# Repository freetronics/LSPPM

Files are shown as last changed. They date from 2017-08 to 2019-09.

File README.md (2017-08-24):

Freetronics LibreSat Payload Processor Module
=============================================
Copyright 2013-2017 Freetronics Pty Ltd  
Freetronics site:  www.freetronics.com  
Freetronics email: info@freetronics.com  

A CubeSat payload board that incorporates 16 processor nodes for
running experiments, and a supervisor processor node to control
the experiment nodes.

A previous version of this board flew in space on ArduSat-X and
ArduSat-1.

Features:

 * 16 x processor nodes, each with an ATmega328P MCU
 * Each processor node runs the Arduino bootloader
 * 1 x supervisor node with an ATmega2561
 * Micro SD card slot connected to supervisor
 * All MCUs and sensors on a shared I2C bus
 * All I2C devices use bidirectional isolation circuits to allow continued operation of the system with failed devices
 * Processor node UARTs connected via multiplexers to the supervisor's first UART
 * 5V serial debug console with standard FTDI-style pinout on supervisor's second UART
 * Each processor node can be powered down independently by the supervisor
 * Each processor node can be reset using an I2C latch by the supervisor
 * Each MCU has an independent crystal for maximum reliability
 * TX, RX, and D13 LEDs on every processor node
 * Top and bottom temperature sensors on I2C bus with "disable" option to prevent address collisions
 * Requires external 5V and 3.3V supply
 * Current consumption monitoring of both power rails by the supervisor
 * Stackable CubeSat bus connectors
 * Conforms to CubeSat mechanical standards for dimensions and mounting
 * Selectable power bus connections
 * Optional I2C satellite bus pull-ups
 * I2C headers for spectrometer, Geiger counter, and bottom plate sensor assembly
 * GPS header with UART connections to node 11 via 3.3V level shifters
 * Switchable power supply to GPS header controlled by supervisor
 * Stackable CubeSat Bus connectors

Specifications:

 * Dimensions: 95.45mm x 90.3mm
 * PCB material: FR4 fibreglass (requires out-gassing before vacuum use)
 * PCB finish: ENIG (electroless nickel immersion gold) recommended
 * Module mass: 37 grams
 * Connector mass (pair): 15 grams
 * Total assembled mass including solder: 54 grams

More information is available at:

  http://www.freetronics.com.au/lsppm

INSTALLATION
------------
The design is saved as an EAGLE project. EAGLE PCB design software is
available from www.cadsoftusa.com free for non-commercial use. To use
this project download it and place the directory containing these files
into the "eagle" directory on your computer. Then open EAGLE and
navigate to the project. 

DISTRIBUTION
------------
The specific terms of distribution of this project are governed by the
license referenced below.

LICENSE
-------
Licensed under the TAPR Open Hardware License (www.tapr.org/OHL).
The "license" folder within this repository also contains a copy of
this license in plain text format.

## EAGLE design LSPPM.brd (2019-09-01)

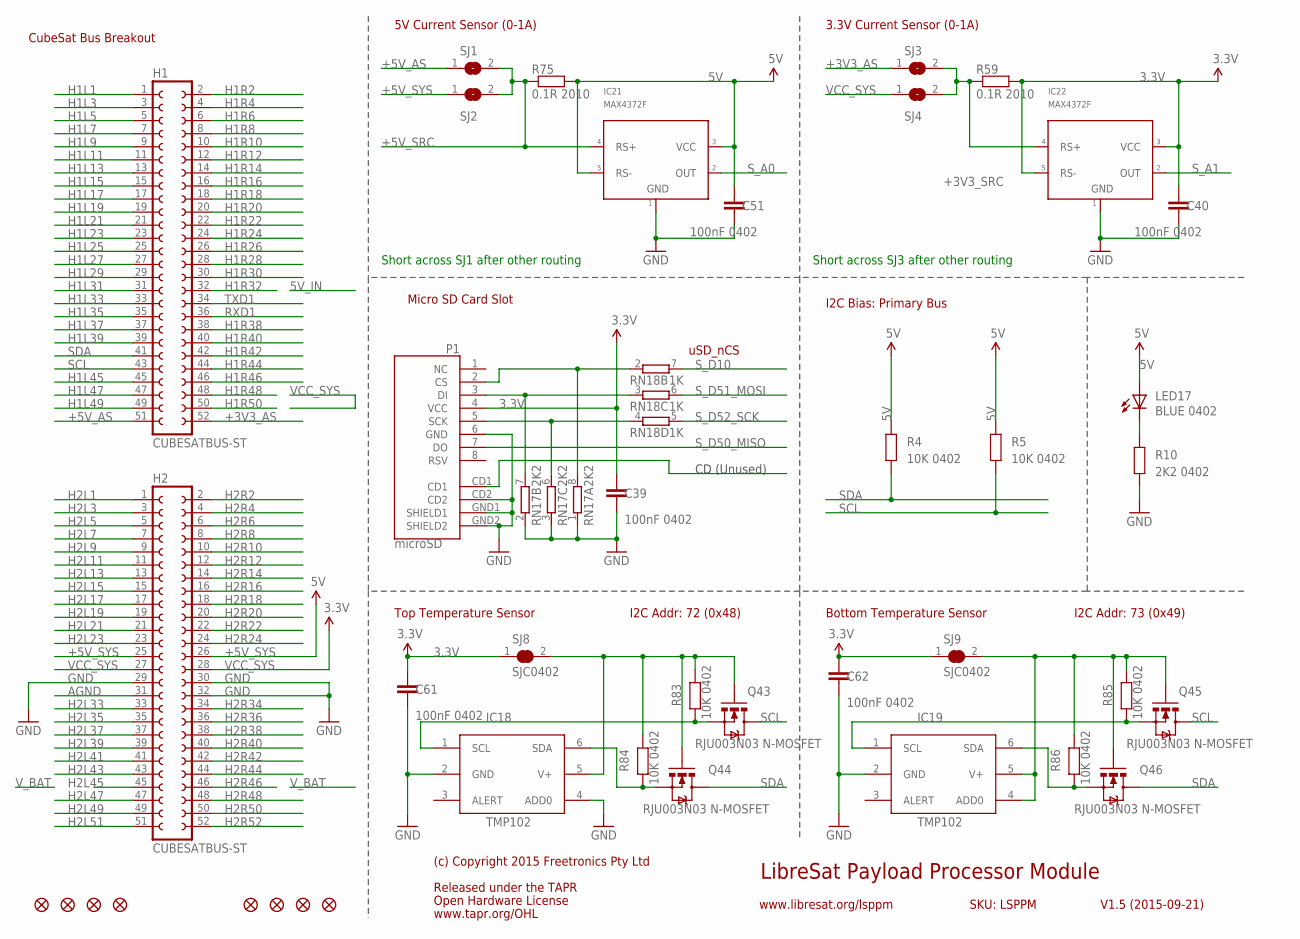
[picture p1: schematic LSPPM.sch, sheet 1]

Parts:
C39, C40, C51, C61, C62: 100nF 0402; C0402
FID1, FID2, FID3, FID4, FID5, FID6, FID7, FID8: FIDUCIAL1X2.5; FIDUCIAL-1X2.5
H1, H2: CUBESATBUS-ST
IC18, IC19: TMP102; SOT563
IC21, IC22: MAX4372F; SOT23-5
LED17: BLUE 0402; LED-0402
P1: microSD; MICRO-SD-SOCKET-PP
Q43, Q44, Q45, Q46: RJU003N03 N-MOSFET; SOT32-3
R4, R5, R83, R84, R85, R86: 10K 0402; R0402
R10: 2K2 0402; R0402
R59, R75: 0.1R 2010; R2010
RN17: 2K2; CAY16
RN18: 1K; CAY16
SJ1, SJ2, SJ3, SJ4: SJ
SJ8, SJ9: SJC0402; 0402SJC

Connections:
3.3V: C39.1, C40.1, C61.1, C62.1, IC22.3 (VCC), IC22.5 (RS-), P1.4 (VCC), R59.2, SJ8.1, SJ9.1; also elsewhere on the board
5V: C51.1, IC21.3 (VCC), IC21.5 (RS-), LED17.A, R4.2, R5.2, R75.2; also elsewhere on the board
+3V3_AS: H1.52, SJ3.1
+3V3_SRC: IC22.4 (RS+), R59.1, SJ3.2, SJ4.2
+5V_AS: H1.51, SJ1.1
+5V_SRC: IC21.4 (RS+), R75.1, SJ1.2, SJ2.2; also elsewhere on the board
+5V_SYS: H2.25, H2.26, SJ2.1
AGND: H2.31
GND: C39.2, C40.2, C51.2, C61.2, C62.2, H2.29, H2.30, H2.32, IC18.2 (GND), IC18.4 (ADD0), IC19.2 (GND), IC21.1 (GND), IC22.1 (GND), P1.6 (GND), P1.CD2, P1.GND1 (SHIELD1), P1.GND2 (SHIELD2), R10.1, RN17.1, RN17.2 (1), RN17.3 (1); also elsewhere on the board
H1L1: H1.1
H1L3: H1.3
H1L5: H1.5
H1L7: H1.7
H1L9: H1.9
H1L11: H1.11
H1L13: H1.13
H1L15: H1.15
H1L17: H1.17
H1L19: H1.19
H1L21: H1.21
H1L23: H1.23
H1L25: H1.25
H1L27: H1.27
H1L29: H1.29
H1L31: H1.31
H1L33: H1.33
H1L35: H1.35
H1L37: H1.37
H1L39: H1.39
H1L45: H1.45
H1L47: H1.47
H1L49: H1.49
H1R2: H1.2
H1R4: H1.4
H1R6: H1.6
H1R8: H1.8
H1R10: H1.10
H1R12: H1.12
H1R14: H1.14
H1R16: H1.16
H1R18: H1.18
H1R20: H1.20
H1R22: H1.22
H1R24: H1.24
H1R26: H1.26
H1R28: H1.28
H1R30: H1.30
H1R32: H1.32
H1R38: H1.38
H1R40: H1.40
H1R42: H1.42
H1R44: H1.44
H1R46: H1.46
H1R48: H1.48
H1R50: H1.50
H2L1: H2.1
H2L3: H2.3
H2L5: H2.5
H2L7: H2.7
H2L9: H2.9
H2L11: H2.11
H2L13: H2.13
H2L15: H2.15
H2L17: H2.17
H2L19: H2.19
H2L21: H2.21
H2L23: H2.23
H2L33: H2.33
H2L35: H2.35
H2L37: H2.37
H2L39: H2.39
H2L41: H2.41
H2L43: H2.43
H2L45: H2.45
H2L47: H2.47
H2L49: H2.49
H2L51: H2.51
H2R2: H2.2
H2R4: H2.4
H2R6: H2.6
H2R8: H2.8
H2R10: H2.10
H2R12: H2.12
H2R14: H2.14
H2R16: H2.16
H2R18: H2.18
H2R20: H2.20
H2R22: H2.22
H2R24: H2.24
H2R34: H2.34
H2R36: H2.36
H2R38: H2.38
H2R40: H2.40
H2R42: H2.42
H2R44: H2.44
H2R46: H2.46
H2R48: H2.48
H2R50: H2.50
H2R52: H2.52
unnamed: LED17.C, R10.2
unnamed: P1.2 (CS), RN17.8 (2), RN18.2 (1)
unnamed: P1.3 (DI), RN17.7 (2), RN18.3 (1)
unnamed: P1.5 (SCK), RN17.6 (2), RN18.4 (1)
unnamed: IC18.1 (SCL), Q43.2 (S), R83.1
unnamed: IC18.6 (SDA), Q44.2 (S), R84.1
unnamed: IC19.6 (SDA), Q46.2 (S), R86.1
unnamed: IC19.1 (SCL), Q45.2 (S), R85.1
unnamed: IC18.5 (V+), Q43.1 (G), Q44.1 (G), R83.2, R84.2, SJ8.2
unnamed: IC19.4 (ADD0), IC19.5 (V+), Q45.1 (G), Q46.1 (G), R85.2, R86.2, SJ9.2
RXD1: H1.36; also elsewhere on the board
SCL: H1.43, Q43.3 (D), Q45.3 (D), R5.1; also elsewhere on the board
SDA: H1.41, Q44.3 (D), Q46.3 (D), R4.1; also elsewhere on the board
S_A0: IC21.2 (OUT); also elsewhere on the board
S_A1: IC22.2 (OUT); also elsewhere on the board
S_D10: RN18.7 (2); also elsewhere on the board
S_D50_MISO: P1.7 (DO); also elsewhere on the board
S_D51_MOSI: RN18.6 (2); also elsewhere on the board
S_D52_SCK: RN18.5 (2); also elsewhere on the board
TXD1: H1.34; also elsewhere on the board
VCC_SYS: H2.27, H2.28, SJ4.1

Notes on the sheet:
LibreSat Payload Processor Module
V1.5 (2015-09-21)
www.libresat.org/lsppm
SKU: LSPPM
CubeSat Bus Breakout
Released under the TAPR
Open Hardware License
www.tapr.org/OHL
(c) Copyright 2015 Freetronics Pty Ltd
I2C Bias: Primary Bus
5V Current Sensor (0-1A)
3.3V Current Sensor (0-1A)
Top Temperature Sensor
Bottom Temperature Sensor
I2C Addr: 72 (0x48)
I2C Addr: 73 (0x49)
Short across SJ1 after other routing
uSD_nCS
Micro SD Card Slot
CD (Unused)
Short across SJ3 after other routing

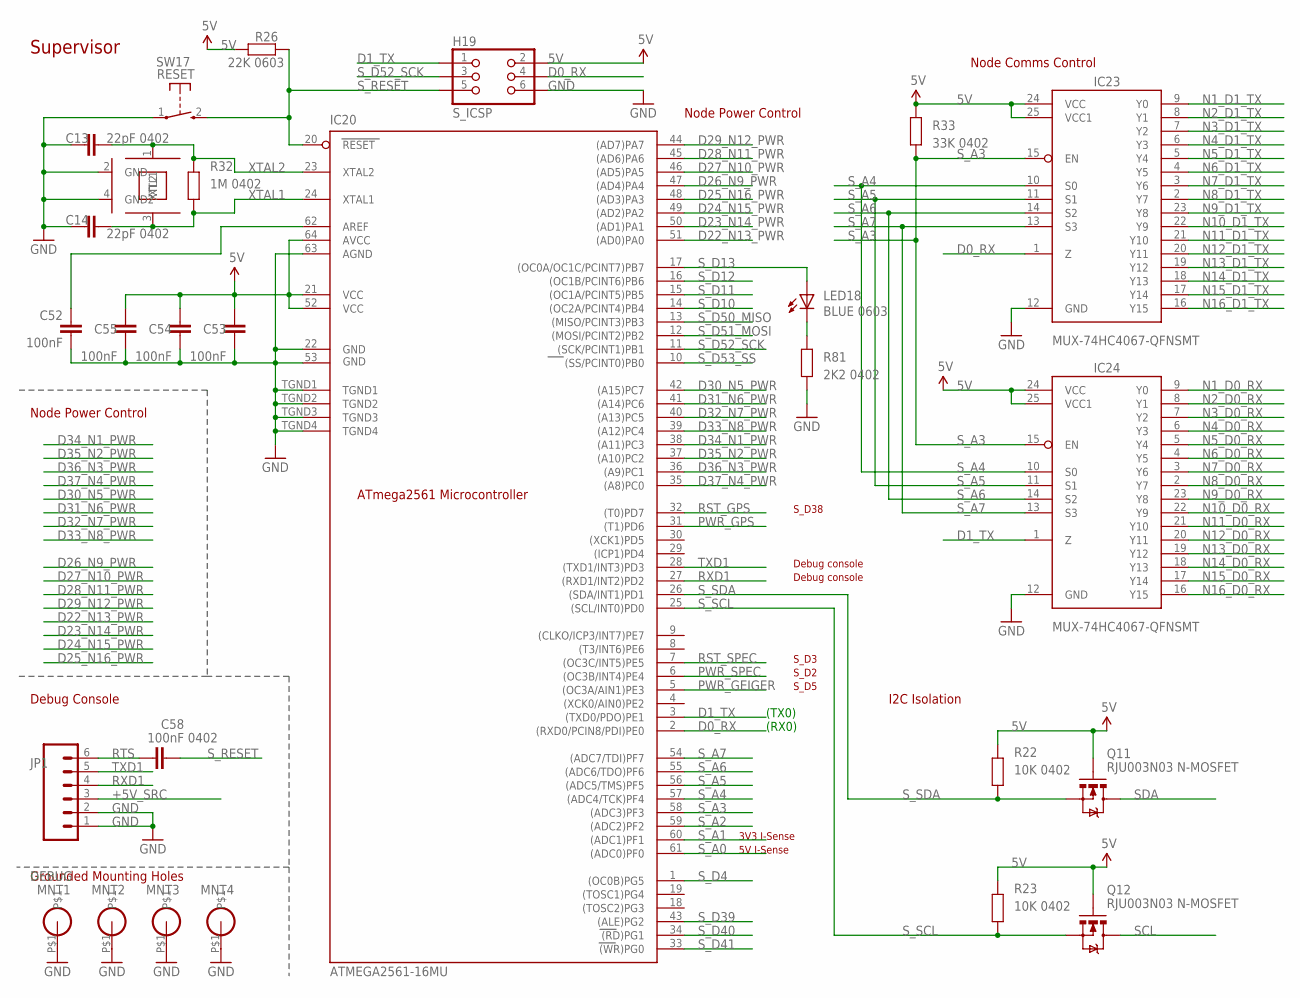
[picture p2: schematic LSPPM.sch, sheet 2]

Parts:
C13, C14: 22pF 0402; C0402
C52, C53, C54, C55: 100nF; C0402
C58: 100nF 0402; C0402
H19: S_ICSP; 2X03-ICSP
IC20: ATMEGA2561-16MU; MLF64
IC23, IC24: MUX-74HC4067-QFNSMT; DHVQFN24
JP1: DEBUG; 1X06-P-RA
LED18: BLUE 0603; LED-0402
MNT1, MNT2, MNT3, MNT4: HOLE3.2MM; HOLE32
Q11, Q12: RJU003N03 N-MOSFET; SOT32-3
R22, R23: 10K 0402; R0402
R26: 22K 0603; R0402
R32: 1M 0402; R0402
R33: 33K 0402; R0402
R81: 2K2 0402; R0402
SW17: RESET; TACTILE_SMT_3X4X2
XTL17: SMD3225-16MHZ 3.2 x 2.5mm crystal; CRYSTAL-SMD-3X2

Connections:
5V: C53.1, C54.1, C55.1, H19.2, IC20.21 (VCC), IC20.52 (VCC1), IC20.64 (AVCC), IC23.24 (VCC), IC23.25 (VCC1), IC24.24 (VCC), IC24.25 (VCC1), Q11.1 (G), Q12.1 (G), R22.2, R23.2, R26.2, R33.2; also elsewhere on the board
+5V_SRC: JP1.3; also elsewhere on the board
D0_RX: H19.4, IC20.2 ((RXD0/PCIN8/PDI)PE0), IC23.1 (Z)
D1_TX: H19.1, IC20.3 ((TXD0/PDO)PE1), IC24.1 (Z)
D22_N13_PWR: IC20.51 ((AD0)PA0); also elsewhere on the board
D23_N14_PWR: IC20.50 ((AD1)PA1); also elsewhere on the board
D24_N15_PWR: IC20.49 ((AD2)PA2); also elsewhere on the board
D25_N16_PWR: IC20.48 ((AD3)PA3); also elsewhere on the board
D26_N9_PWR: IC20.47 ((AD4)PA4); also elsewhere on the board
D27_N10_PWR: IC20.46 ((AD5)PA5); also elsewhere on the board
D28_N11_PWR: IC20.45 ((AD6)PA6); also elsewhere on the board
D29_N12_PWR: IC20.44 ((AD7)PA7); also elsewhere on the board
D30_N5_PWR: IC20.42 ((A15)PC7); also elsewhere on the board
D31_N6_PWR: IC20.41 ((A14)PC6); also elsewhere on the board
D32_N7_PWR: IC20.40 ((A13)PC5); also elsewhere on the board
D33_N8_PWR: IC20.39 ((A12)PC4); also elsewhere on the board
D34_N1_PWR: IC20.38 ((A11)PC3); also elsewhere on the board
D35_N2_PWR: IC20.37 ((A10)PC2); also elsewhere on the board
D36_N3_PWR: IC20.36 ((A9)PC1); also elsewhere on the board
D37_N4_PWR: IC20.35 ((A8)PC0); also elsewhere on the board
GND: C13.1, C14.1, C52.2, C53.2, C54.2, C55.2, H19.6, IC20.22 (GND), IC20.53 (GND1), IC20.63 (AGND), IC20.TGND1, IC20.TGND2, IC20.TGND3, IC20.TGND4, IC23.12 (GND), IC24.12 (GND), JP1.1, JP1.2, MNT1.P$1, MNT2.P$1, MNT3.P$1, MNT4.P$1, R81.1, SW17.1, XTL17.2 (GND), XTL17.4 (GND2); also elsewhere on the board
N1_D0_RX: IC24.9 (Y0); also elsewhere on the board
N1_D1_TX: IC23.9 (Y0); also elsewhere on the board
N2_D0_RX: IC24.8 (Y1); also elsewhere on the board
N2_D1_TX: IC23.8 (Y1); also elsewhere on the board
N3_D0_RX: IC24.7 (Y2); also elsewhere on the board
N3_D1_TX: IC23.7 (Y2); also elsewhere on the board
N4_D0_RX: IC24.6 (Y3); also elsewhere on the board
N4_D1_TX: IC23.6 (Y3); also elsewhere on the board
N5_D0_RX: IC24.5 (Y4); also elsewhere on the board
N5_D1_TX: IC23.5 (Y4); also elsewhere on the board
N6_D0_RX: IC24.4 (Y5); also elsewhere on the board
N6_D1_TX: IC23.4 (Y5); also elsewhere on the board
N7_D0_RX: IC24.3 (Y6); also elsewhere on the board
N7_D1_TX: IC23.3 (Y6); also elsewhere on the board
N8_D0_RX: IC24.2 (Y7); also elsewhere on the board
N8_D1_TX: IC23.2 (Y7); also elsewhere on the board
N9_D0_RX: IC24.23 (Y8); also elsewhere on the board
N9_D1_TX: IC23.23 (Y8); also elsewhere on the board
N10_D0_RX: IC24.22 (Y9); also elsewhere on the board
N10_D1_TX: IC23.22 (Y9); also elsewhere on the board
N11_D0_RX: IC24.21 (Y10); also elsewhere on the board
N11_D1_TX: IC23.21 (Y10); also elsewhere on the board
N12_D0_RX: IC24.20 (Y11); also elsewhere on the board
N12_D1_TX: IC23.20 (Y11); also elsewhere on the board
N13_D0_RX: IC24.19 (Y12); also elsewhere on the board
N13_D1_TX: IC23.19 (Y12); also elsewhere on the board
N14_D0_RX: IC24.18 (Y13); also elsewhere on the board
N14_D1_TX: IC23.18 (Y13); also elsewhere on the board
N15_D0_RX: IC24.17 (Y14); also elsewhere on the board
N15_D1_TX: IC23.17 (Y14); also elsewhere on the board
N16_D0_RX: IC24.16 (Y15); also elsewhere on the board
N16_D1_TX: IC23.16 (Y15); also elsewhere on the board
unnamed: C52.1, IC20.62 (AREF)
unnamed: LED18.C, R81.2
PWR_GEIGER: IC20.5 ((OC3A/AIN1)PE3); also elsewhere on the board
PWR_GPS: IC20.31 ((T1)PD6); also elsewhere on the board
PWR_SPEC: IC20.6 ((OC3B/INT4)PE4); also elsewhere on the board
RST_GPS: IC20.32 ((T0)PD7); also elsewhere on the board
RST_SPEC: IC20.7 ((OC3C/INT5)PE5); also elsewhere on the board
RTS: C58.1, JP1.6
RXD1: IC20.27 ((RXD1/INT2)PD2), JP1.4; also elsewhere on the board
SCL: Q12.3 (D); also elsewhere on the board
SDA: Q11.3 (D); also elsewhere on the board
S_A0: IC20.61 ((ADC0)PF0); also elsewhere on the board
S_A1: IC20.60 ((ADC1)PF1); also elsewhere on the board
S_A2: IC20.59 ((ADC2)PF2)
S_A3: IC20.58 ((ADC3)PF3), IC23.15 (EN), IC24.15 (EN), R33.1
S_A4: IC20.57 ((ADC4/TCK)PF4), IC23.10 (S0), IC24.10 (S0)
S_A5: IC20.56 ((ADC5/TMS)PF5), IC23.11 (S1), IC24.11 (S1)
S_A6: IC20.55 ((ADC6/TDO)PF6), IC23.14 (S2), IC24.14 (S2)
S_A7: IC20.54 ((ADC7/TDI)PF7), IC23.13 (S3), IC24.13 (S3)
S_D4: IC20.1 ((OC0B)PG5)
S_D10: IC20.14 ((OC2A/PCINT4)PB4); also elsewhere on the board
S_D11: IC20.15 ((OC1A/PCINT5)PB5)
S_D12: IC20.16 ((OC1B/PCINT6)PB6)
S_D13: IC20.17 ((OC0A/OC1C/PCINT7)PB7), LED18.A
S_D39: IC20.43 ((ALE)PG2)
S_D40: IC20.34 ((RD)PG1)
S_D41: IC20.33 ((WR)PG0)
S_D50_MISO: IC20.13 ((MISO/PCINT3)PB3); also elsewhere on the board
S_D51_MOSI: IC20.12 ((MOSI/PCINT2)PB2); also elsewhere on the board
S_D52_SCK: H19.3, IC20.11 ((SCK/PCINT1)PB1); also elsewhere on the board
S_D53_SS: IC20.10 ((SS/PCINT0)PB0)
S_RESET: C58.2, H19.5, IC20.20 (RESET), R26.1, SW17.2 (S)
S_SCL: IC20.25 ((SCL/INT0)PD0), Q12.2 (S), R23.1
S_SDA: IC20.26 ((SDA/INT1)PD1), Q11.2 (S), R22.1
TXD1: IC20.28 ((TXD1/INT3)PD3), JP1.5; also elsewhere on the board
XTAL1: C14.2, IC20.24 (XTAL1), R32.1, XTL17.3 (XTL2)
XTAL2: C13.2, IC20.23 (XTAL2), R32.2, XTL17.1 (XTL1)

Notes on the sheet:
Supervisor
Node Comms Control
Node Power Control
I2C Isolation
ATmega2561 Microcontroller
(TX0)
(RX0)
Grounded Mounting Holes
Debug Console
5V I-Sense
3V3 I-Sense
S_D5
S_D2
S_D3
Debug console
S_D38

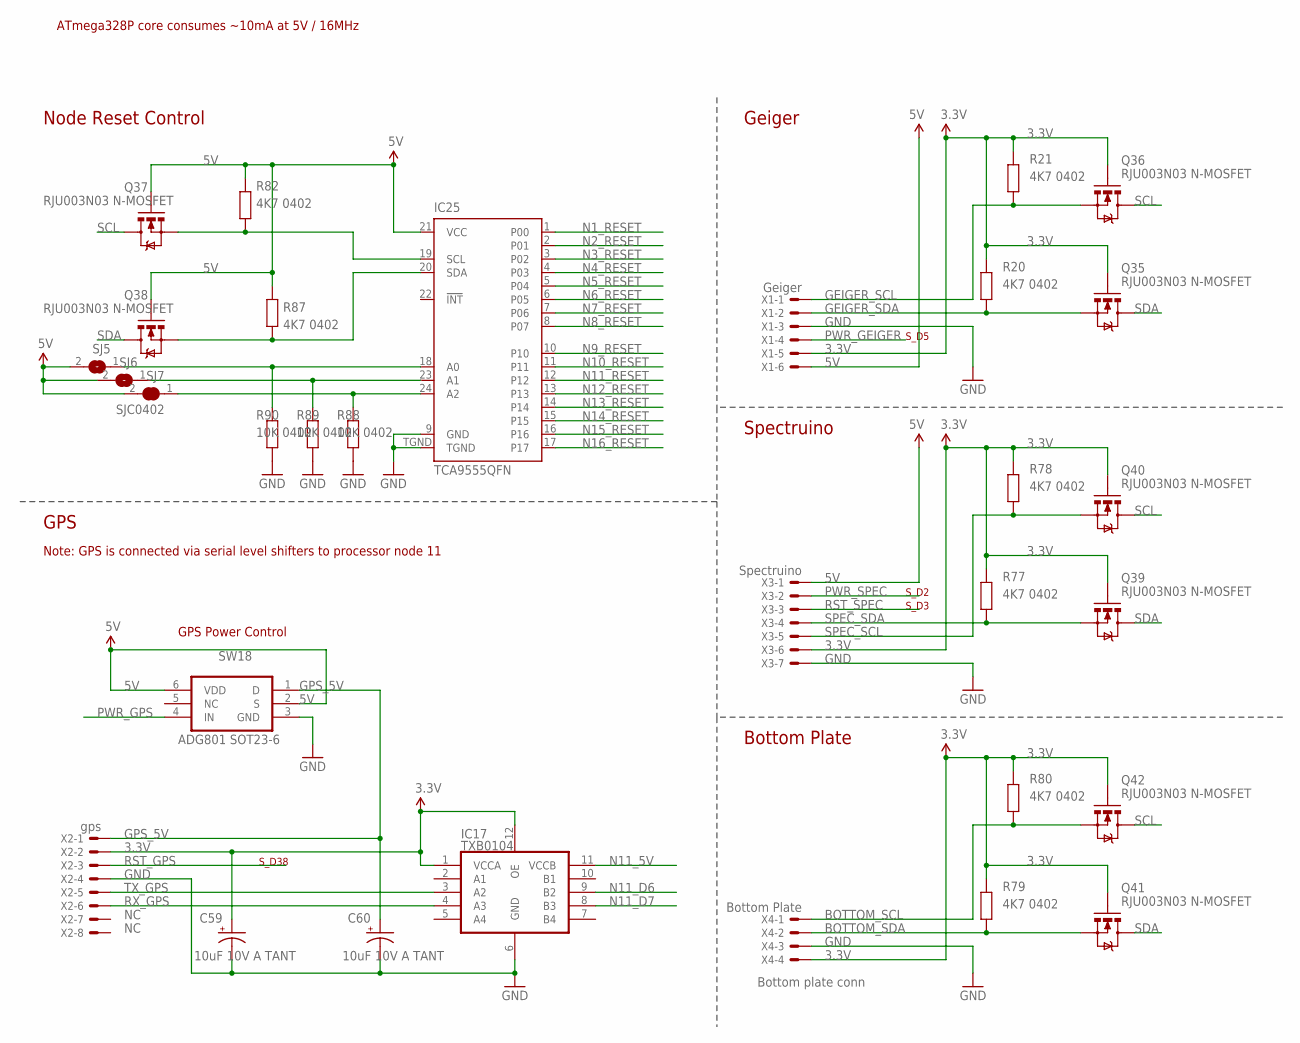
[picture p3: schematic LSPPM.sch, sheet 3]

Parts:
C59, C60: 10uF 10V A TANT; EIA3216
IC17: TXB0104; QFN-12
IC25: TCA9555QFN; QFN-24
Q35, Q36, Q37, Q38, Q39, Q40, Q41, Q42: RJU003N03 N-MOSFET; SOT32-3
R20, R21, R77, R78, R79, R80, R82, R87: 4K7 0402; R0402
R88, R89, R90: 10K 0402; R0402
SJ5, SJ6: SJ0402O; 0402SJO
SJ7: SJC0402; 0402SJC
SW18: ADG801 SOT23-6; SOT23-6
X1: Geiger; 53398-06
X2: gps; 53398-08
X3: Spectruino; 53398-07
X4: Bottom Plate; 53398-04

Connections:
3.3V: C59.A (+), IC17.1 (VCCA), IC17.12 (OE), Q35.1 (G), Q36.1 (G), Q39.1 (G), Q40.1 (G), Q41.1 (G), Q42.1 (G), R20.2, R21.2, R77.2, R78.2, R79.2, R80.2, X1.5, X2.2, X3.6, X4.4; also elsewhere on the board
5V: IC25.21 (VCC), Q37.1 (G), Q38.1 (G), R82.2, R87.2, SJ5.2, SJ6.2, SJ7.2, SW18.2 (S), SW18.6 (VDD), X1.6, X3.1; also elsewhere on the board
BOTTOM_SCL: Q42.2 (S), R80.1, X4.1
BOTTOM_SDA: Q41.2 (S), R79.1, X4.2
GEIGER_SCL: Q36.2 (S), R21.1, X1.1
GEIGER_SDA: Q35.2 (S), R20.1, X1.2
GND: C59.C (-), C60.C (-), IC17.6 (GND), IC25.9 (GND), IC25.TGND, R88.1, R89.1, R90.1, SW18.3 (GND), X1.3, X2.4, X3.7, X4.3; also elsewhere on the board
GPS_5V: C60.A (+), SW18.1 (D), X2.1
N1_RESET: IC25.1 (P00); also elsewhere on the board
N2_RESET: IC25.2 (P01); also elsewhere on the board
N3_RESET: IC25.3 (P02); also elsewhere on the board
N4_RESET: IC25.4 (P03); also elsewhere on the board
N5_RESET: IC25.5 (P04); also elsewhere on the board
N6_RESET: IC25.6 (P05); also elsewhere on the board
N7_RESET: IC25.7 (P06); also elsewhere on the board
N8_RESET: IC25.8 (P07); also elsewhere on the board
N9_RESET: IC25.10; also elsewhere on the board
N10_RESET: IC25.11; also elsewhere on the board
N11_5V: IC17.11 (VCCB); also elsewhere on the board
N11_D6: IC17.9 (B2); also elsewhere on the board
N11_D7: IC17.8 (B3); also elsewhere on the board
N11_RESET: IC25.12; also elsewhere on the board
N12_RESET: IC25.13; also elsewhere on the board
N13_RESET: IC25.14; also elsewhere on the board
N14_RESET: IC25.15; also elsewhere on the board
N15_RESET: IC25.16; also elsewhere on the board
N16_RESET: IC25.17; also elsewhere on the board
unnamed: IC25.18 (A0), R90.2, SJ5.1
unnamed: IC25.23 (A1), R89.2, SJ6.1
unnamed: IC25.24 (A2), R88.2, SJ7.1
unnamed: IC25.19 (SCL), Q37.2 (S), R82.1
unnamed: IC25.20 (SDA), Q38.2 (S), R87.1
PWR_GEIGER: X1.4; also elsewhere on the board
PWR_GPS: SW18.4 (IN); also elsewhere on the board
PWR_SPEC: X3.2; also elsewhere on the board
RST_GPS: X2.3; also elsewhere on the board
RST_SPEC: X3.3; also elsewhere on the board
RX_GPS: IC17.4 (A3), X2.6
SCL: Q36.3 (D), Q37.3 (D), Q40.3 (D), Q42.3 (D); also elsewhere on the board
SDA: Q35.3 (D), Q38.3 (D), Q39.3 (D), Q41.3 (D); also elsewhere on the board
SPEC_SCL: Q40.2 (S), R78.1, X3.5
SPEC_SDA: Q39.2 (S), R77.1, X3.4
TX_GPS: IC17.3 (A2), X2.5

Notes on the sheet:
Node Reset Control
Bottom plate conn
Geiger
Spectruino
Bottom Plate
GPS
Note: GPS is connected via serial level shifters to processor node 11
S_D3
S_D2
S_D5
ATmega328P core consumes ~10mA at 5V / 16MHz
S_D38
GPS Power Control

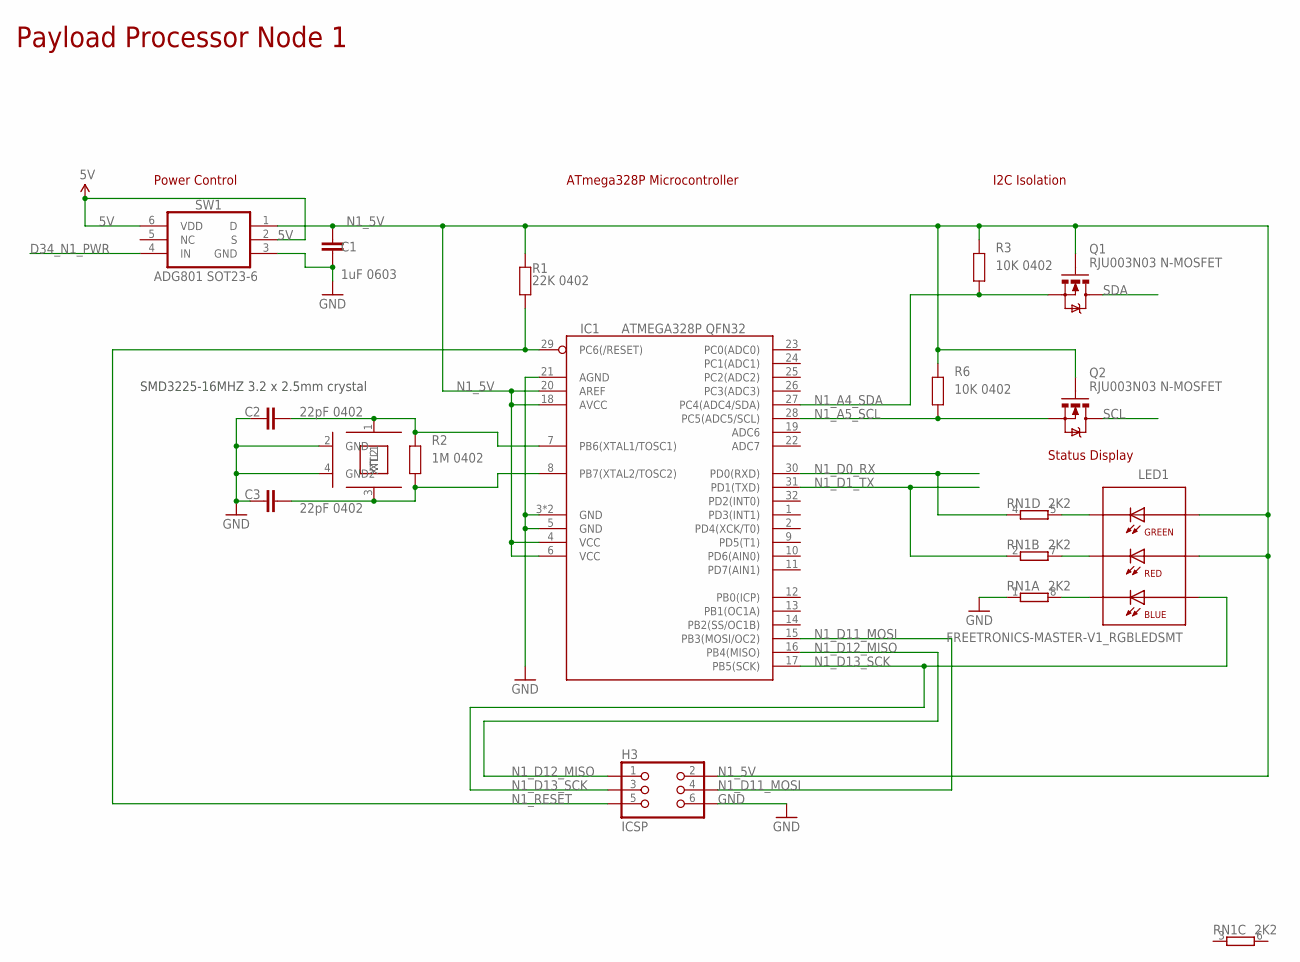
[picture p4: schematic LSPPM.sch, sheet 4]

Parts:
C1: 1uF 0603; C0603
C2, C3: 22pF 0402; C0402
H3: ICSP; M2X3-2MM
IC1: ATMEGA328P QFN32; MLF32
LED1: FREETRONICS-MASTER-V1_RGBLEDSMT; FREETRONICS-MASTER-V1_19-337
Q1, Q2: RJU003N03 N-MOSFET; SOT32-3
R1: 22K 0402; R0402
R2: 1M 0402; R0402
R3, R6: 10K 0402; R0402
RN1: 2K2; CAY16
SW1: ADG801 SOT23-6; SOT23-6
XTL1: SMD3225-16MHZ 3.2 x 2.5mm crystal; CRYSTAL-SMD-3X2

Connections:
5V: SW1.2 (S), SW1.6 (VDD); also elsewhere on the board
D34_N1_PWR: SW1.4 (IN); also elsewhere on the board
GND: C1.2, C2.1, C3.1, H3.6, IC1.3 (GND), IC1.5 (GND), IC1.21 (AGND), IC1.TGND (GND), RN1.1, SW1.3 (GND), XTL1.2 (GND), XTL1.4 (GND2); also elsewhere on the board
N1_5V: C1.1, H3.2, IC1.4 (VCC), IC1.6 (VCC), IC1.18 (AVCC), IC1.20 (AREF), LED1.5 (A-R), LED1.6 (A-G), Q1.1 (G), Q2.1 (G), R1.2, R3.2, R6.2, SW1.1 (D)
N1_A4_SDA: IC1.27 (PC4(ADC4/SDA)), Q1.2 (S), R3.1
N1_A5_SCL: IC1.28 (PC5(ADC5/SCL)), Q2.2 (S), R6.1
N1_D0_RX: IC1.30 (PD0(RXD)), RN1.4 (1); also elsewhere on the board
N1_D1_TX: IC1.31 (PD1(TXD)), RN1.2 (1); also elsewhere on the board
N1_D11_MOSI: H3.4, IC1.15 (PB3(MOSI/OC2))
N1_D12_MISO: H3.1, IC1.16 (PB4(MISO))
N1_D13_SCK: H3.3, IC1.17 (PB5(SCK)), LED1.4 (A-B)
N1_RESET: H3.5, IC1.29 (PC6(/RESET)), R1.1; also elsewhere on the board
unnamed: LED1.3 (C-G), RN1.5 (2)
unnamed: C3.2, IC1.8 (PB7(XTAL2/TOSC2)), R2.1, XTL1.3 (XTL2)
unnamed: C2.2, IC1.7 (PB6(XTAL1/TOSC1)), R2.2, XTL1.1 (XTL1)
unnamed: LED1.2 (C-R), RN1.7 (2)
unnamed: LED1.1 (C-B), RN1.8 (2)
SCL: Q2.3 (D); also elsewhere on the board
SDA: Q1.3 (D); also elsewhere on the board

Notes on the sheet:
Payload Processor Node 1
ATmega328P Microcontroller
I2C Isolation
Status Display
Power Control
SMD3225-16MHZ 3.2 x 2.5mm crystal

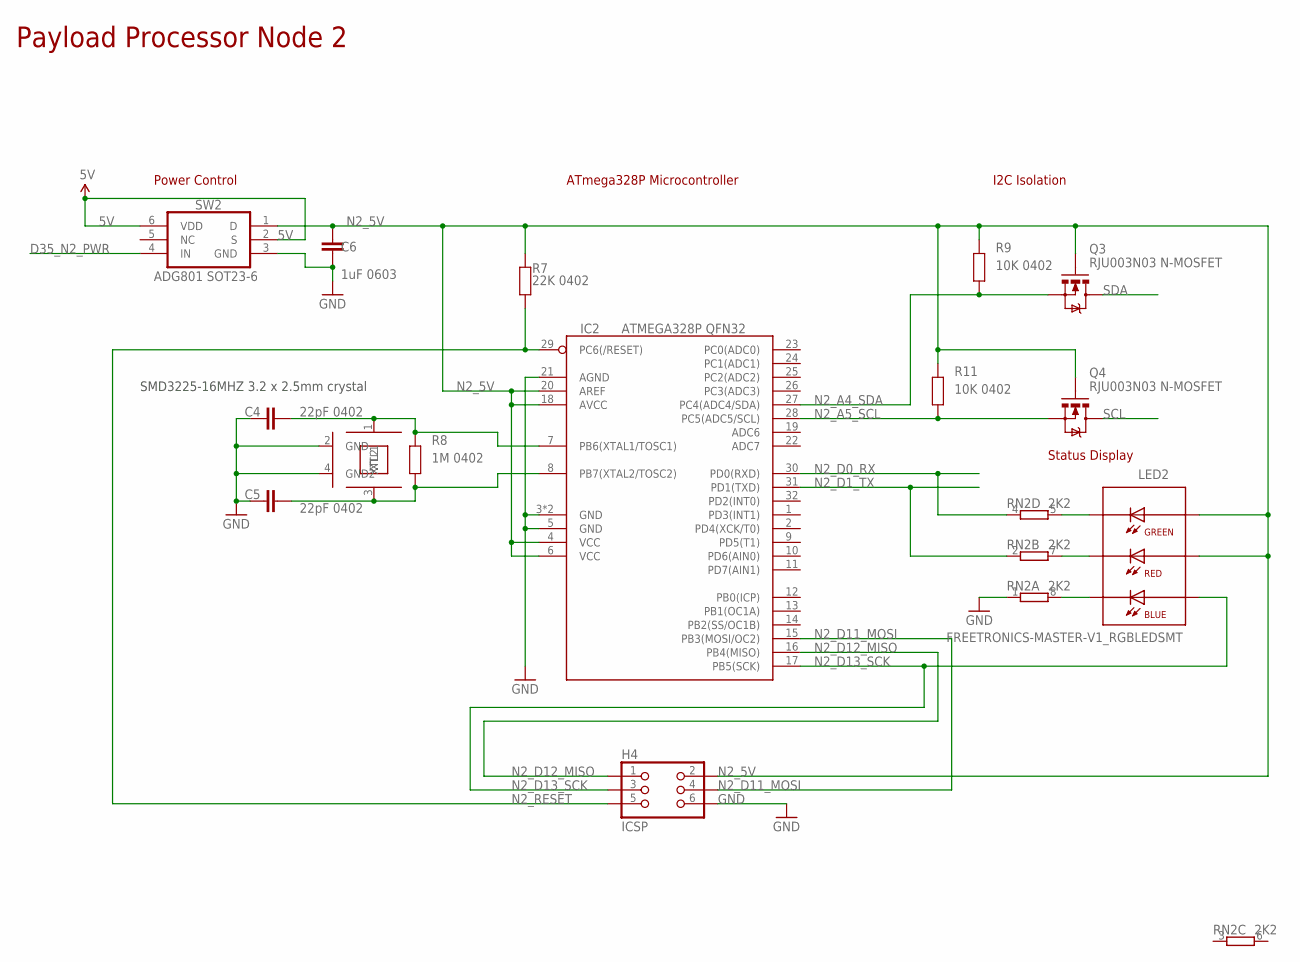
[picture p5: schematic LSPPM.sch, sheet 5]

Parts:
C4, C5: 22pF 0402; C0402
C6: 1uF 0603; C0603
H4: ICSP; M2X3-2MM
IC2: ATMEGA328P QFN32; MLF32
LED2: FREETRONICS-MASTER-V1_RGBLEDSMT; FREETRONICS-MASTER-V1_19-337
Q3, Q4: RJU003N03 N-MOSFET; SOT32-3
R7: 22K 0402; R0402
R8: 1M 0402; R0402
R9, R11: 10K 0402; R0402
RN2: 2K2; CAY16
SW2: ADG801 SOT23-6; SOT23-6
XTL2: SMD3225-16MHZ 3.2 x 2.5mm crystal; CRYSTAL-SMD-3X2

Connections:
5V: SW2.2 (S), SW2.6 (VDD); also elsewhere on the board
D35_N2_PWR: SW2.4 (IN); also elsewhere on the board
GND: C4.1, C5.1, C6.2, H4.6, IC2.3 (GND), IC2.5 (GND), IC2.21 (AGND), IC2.TGND (GND), RN2.1, SW2.3 (GND), XTL2.2 (GND), XTL2.4 (GND2); also elsewhere on the board
N2_5V: C6.1, H4.2, IC2.4 (VCC), IC2.6 (VCC), IC2.18 (AVCC), IC2.20 (AREF), LED2.5 (A-R), LED2.6 (A-G), Q3.1 (G), Q4.1 (G), R7.2, R9.2, R11.2, SW2.1 (D)
N2_A4_SDA: IC2.27 (PC4(ADC4/SDA)), Q3.2 (S), R9.1
N2_A5_SCL: IC2.28 (PC5(ADC5/SCL)), Q4.2 (S), R11.1
N2_D0_RX: IC2.30 (PD0(RXD)), RN2.4 (1); also elsewhere on the board
N2_D1_TX: IC2.31 (PD1(TXD)), RN2.2 (1); also elsewhere on the board
N2_D11_MOSI: H4.4, IC2.15 (PB3(MOSI/OC2))
N2_D12_MISO: H4.1, IC2.16 (PB4(MISO))
N2_D13_SCK: H4.3, IC2.17 (PB5(SCK)), LED2.4 (A-B)
N2_RESET: H4.5, IC2.29 (PC6(/RESET)), R7.1; also elsewhere on the board
unnamed: C5.2, IC2.8 (PB7(XTAL2/TOSC2)), R8.1, XTL2.3 (XTL2)
unnamed: C4.2, IC2.7 (PB6(XTAL1/TOSC1)), R8.2, XTL2.1 (XTL1)
unnamed: LED2.2 (C-R), RN2.7 (2)
unnamed: LED2.1 (C-B), RN2.8 (2)
unnamed: LED2.3 (C-G), RN2.5 (2)
SCL: Q4.3 (D); also elsewhere on the board
SDA: Q3.3 (D); also elsewhere on the board

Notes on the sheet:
Payload Processor Node 2
ATmega328P Microcontroller
I2C Isolation
Status Display
Power Control
SMD3225-16MHZ 3.2 x 2.5mm crystal

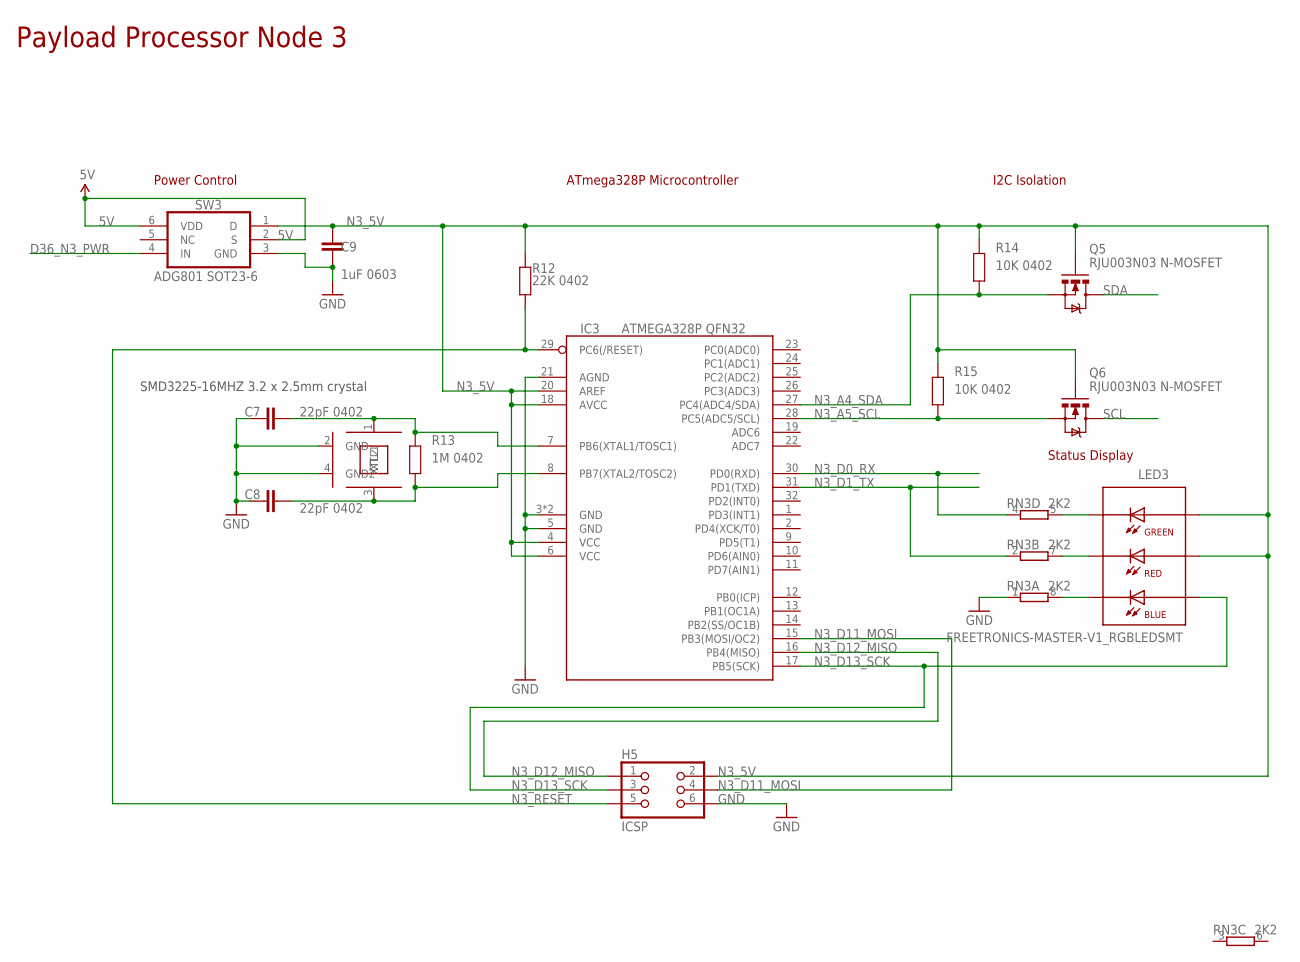
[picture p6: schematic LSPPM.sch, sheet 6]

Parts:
C7, C8: 22pF 0402; C0402
C9: 1uF 0603; C0603
H5: ICSP; M2X3-2MM
IC3: ATMEGA328P QFN32; MLF32
LED3: FREETRONICS-MASTER-V1_RGBLEDSMT; FREETRONICS-MASTER-V1_19-337
Q5, Q6: RJU003N03 N-MOSFET; SOT32-3
R12: 22K 0402; R0402
R13: 1M 0402; R0402
R14, R15: 10K 0402; R0402
RN3: 2K2; CAY16
SW3: ADG801 SOT23-6; SOT23-6
XTL3: SMD3225-16MHZ 3.2 x 2.5mm crystal; CRYSTAL-SMD-3X2

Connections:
5V: SW3.2 (S), SW3.6 (VDD); also elsewhere on the board
D36_N3_PWR: SW3.4 (IN); also elsewhere on the board
GND: C7.1, C8.1, C9.2, H5.6, IC3.3 (GND), IC3.5 (GND), IC3.21 (AGND), IC3.TGND (GND), RN3.1, SW3.3 (GND), XTL3.2 (GND), XTL3.4 (GND2); also elsewhere on the board
N3_5V: C9.1, H5.2, IC3.4 (VCC), IC3.6 (VCC), IC3.18 (AVCC), IC3.20 (AREF), LED3.5 (A-R), LED3.6 (A-G), Q5.1 (G), Q6.1 (G), R12.2, R14.2, R15.2, SW3.1 (D)
N3_A4_SDA: IC3.27 (PC4(ADC4/SDA)), Q5.2 (S), R14.1
N3_A5_SCL: IC3.28 (PC5(ADC5/SCL)), Q6.2 (S), R15.1
N3_D0_RX: IC3.30 (PD0(RXD)), RN3.4 (1); also elsewhere on the board
N3_D1_TX: IC3.31 (PD1(TXD)), RN3.2 (1); also elsewhere on the board
N3_D11_MOSI: H5.4, IC3.15 (PB3(MOSI/OC2))
N3_D12_MISO: H5.1, IC3.16 (PB4(MISO))
N3_D13_SCK: H5.3, IC3.17 (PB5(SCK)), LED3.4 (A-B)
N3_RESET: H5.5, IC3.29 (PC6(/RESET)), R12.1; also elsewhere on the board
unnamed: C8.2, IC3.8 (PB7(XTAL2/TOSC2)), R13.1, XTL3.3 (XTL2)
unnamed: C7.2, IC3.7 (PB6(XTAL1/TOSC1)), R13.2, XTL3.1 (XTL1)
unnamed: LED3.2 (C-R), RN3.7 (2)
unnamed: LED3.1 (C-B), RN3.8 (2)
unnamed: LED3.3 (C-G), RN3.5 (2)
SCL: Q6.3 (D); also elsewhere on the board
SDA: Q5.3 (D); also elsewhere on the board

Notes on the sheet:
Payload Processor Node 3
ATmega328P Microcontroller
I2C Isolation
Status Display
Power Control
SMD3225-16MHZ 3.2 x 2.5mm crystal

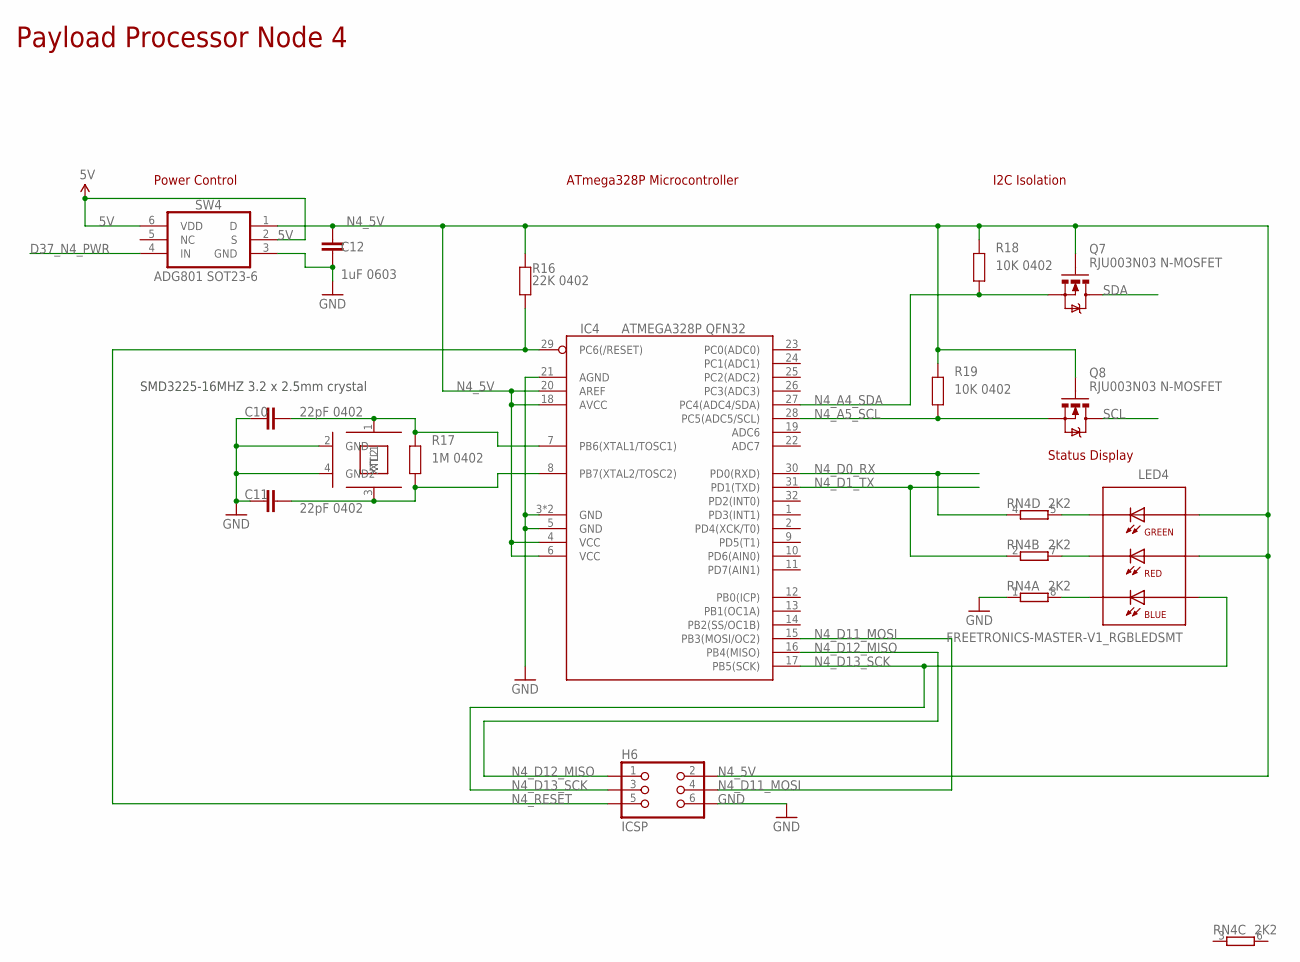
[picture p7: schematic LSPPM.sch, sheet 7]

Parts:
C10, C11: 22pF 0402; C0402
C12: 1uF 0603; C0603
H6: ICSP; M2X3-2MM
IC4: ATMEGA328P QFN32; MLF32
LED4: FREETRONICS-MASTER-V1_RGBLEDSMT; FREETRONICS-MASTER-V1_19-337
Q7, Q8: RJU003N03 N-MOSFET; SOT32-3
R16: 22K 0402; R0402
R17: 1M 0402; R0402
R18, R19: 10K 0402; R0402
RN4: 2K2; CAY16
SW4: ADG801 SOT23-6; SOT23-6
XTL4: SMD3225-16MHZ 3.2 x 2.5mm crystal; CRYSTAL-SMD-3X2

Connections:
5V: SW4.2 (S), SW4.6 (VDD); also elsewhere on the board
D37_N4_PWR: SW4.4 (IN); also elsewhere on the board
GND: C10.1, C11.1, C12.2, H6.6, IC4.3 (GND), IC4.5 (GND), IC4.21 (AGND), IC4.TGND (GND), RN4.1, SW4.3 (GND), XTL4.2 (GND), XTL4.4 (GND2); also elsewhere on the board
N4_5V: C12.1, H6.2, IC4.4 (VCC), IC4.6 (VCC), IC4.18 (AVCC), IC4.20 (AREF), LED4.5 (A-R), LED4.6 (A-G), Q7.1 (G), Q8.1 (G), R16.2, R18.2, R19.2, SW4.1 (D)
N4_A4_SDA: IC4.27 (PC4(ADC4/SDA)), Q7.2 (S), R18.1
N4_A5_SCL: IC4.28 (PC5(ADC5/SCL)), Q8.2 (S), R19.1
N4_D0_RX: IC4.30 (PD0(RXD)), RN4.4 (1); also elsewhere on the board
N4_D1_TX: IC4.31 (PD1(TXD)), RN4.2 (1); also elsewhere on the board
N4_D11_MOSI: H6.4, IC4.15 (PB3(MOSI/OC2))
N4_D12_MISO: H6.1, IC4.16 (PB4(MISO))
N4_D13_SCK: H6.3, IC4.17 (PB5(SCK)), LED4.4 (A-B)
N4_RESET: H6.5, IC4.29 (PC6(/RESET)), R16.1; also elsewhere on the board
unnamed: C11.2, IC4.8 (PB7(XTAL2/TOSC2)), R17.1, XTL4.3 (XTL2)
unnamed: C10.2, IC4.7 (PB6(XTAL1/TOSC1)), R17.2, XTL4.1 (XTL1)
unnamed: LED4.2 (C-R), RN4.7 (2)
unnamed: LED4.1 (C-B), RN4.8 (2)
unnamed: LED4.3 (C-G), RN4.5 (2)
SCL: Q8.3 (D); also elsewhere on the board
SDA: Q7.3 (D); also elsewhere on the board

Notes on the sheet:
Payload Processor Node 4
ATmega328P Microcontroller
I2C Isolation
Status Display
Power Control
SMD3225-16MHZ 3.2 x 2.5mm crystal

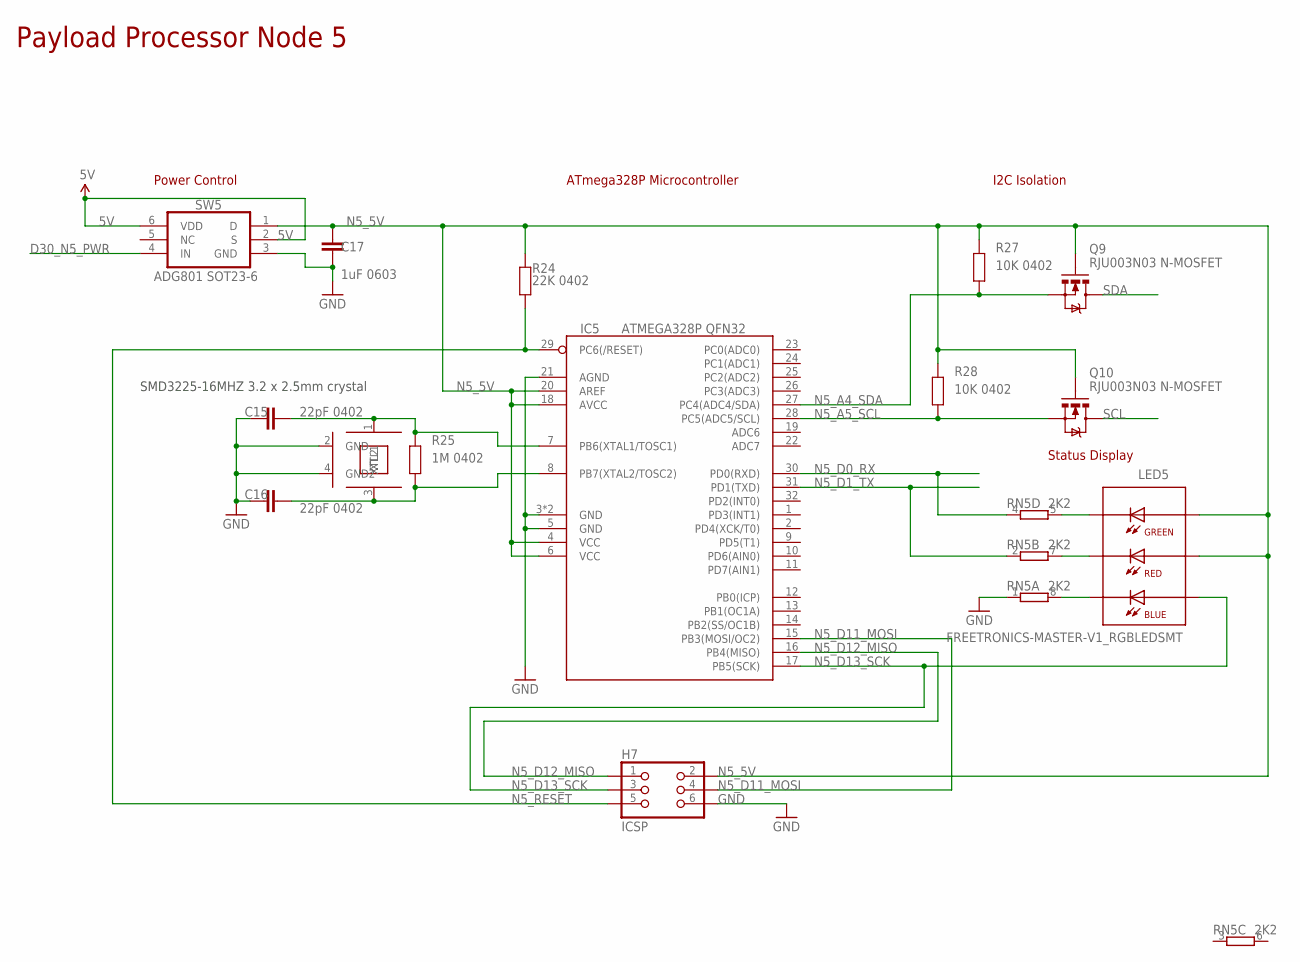
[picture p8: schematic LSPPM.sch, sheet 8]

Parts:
C15, C16: 22pF 0402; C0402
C17: 1uF 0603; C0603
H7: ICSP; M2X3-2MM
IC5: ATMEGA328P QFN32; MLF32
LED5: FREETRONICS-MASTER-V1_RGBLEDSMT; FREETRONICS-MASTER-V1_19-337
Q9, Q10: RJU003N03 N-MOSFET; SOT32-3
R24: 22K 0402; R0402
R25: 1M 0402; R0402
R27, R28: 10K 0402; R0402
RN5: 2K2; CAY16
SW5: ADG801 SOT23-6; SOT23-6
XTL5: SMD3225-16MHZ 3.2 x 2.5mm crystal; CRYSTAL-SMD-3X2

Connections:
5V: SW5.2 (S), SW5.6 (VDD); also elsewhere on the board
D30_N5_PWR: SW5.4 (IN); also elsewhere on the board
GND: C15.1, C16.1, C17.2, H7.6, IC5.3 (GND), IC5.5 (GND), IC5.21 (AGND), IC5.TGND (GND), RN5.1, SW5.3 (GND), XTL5.2 (GND), XTL5.4 (GND2); also elsewhere on the board
N5_5V: C17.1, H7.2, IC5.4 (VCC), IC5.6 (VCC), IC5.18 (AVCC), IC5.20 (AREF), LED5.5 (A-R), LED5.6 (A-G), Q9.1 (G), Q10.1 (G), R24.2, R27.2, R28.2, SW5.1 (D)
N5_A4_SDA: IC5.27 (PC4(ADC4/SDA)), Q9.2 (S), R27.1
N5_A5_SCL: IC5.28 (PC5(ADC5/SCL)), Q10.2 (S), R28.1
N5_D0_RX: IC5.30 (PD0(RXD)), RN5.4 (1); also elsewhere on the board
N5_D1_TX: IC5.31 (PD1(TXD)), RN5.2 (1); also elsewhere on the board
N5_D11_MOSI: H7.4, IC5.15 (PB3(MOSI/OC2))
N5_D12_MISO: H7.1, IC5.16 (PB4(MISO))
N5_D13_SCK: H7.3, IC5.17 (PB5(SCK)), LED5.4 (A-B)
N5_RESET: H7.5, IC5.29 (PC6(/RESET)), R24.1; also elsewhere on the board
unnamed: C16.2, IC5.8 (PB7(XTAL2/TOSC2)), R25.1, XTL5.3 (XTL2)
unnamed: C15.2, IC5.7 (PB6(XTAL1/TOSC1)), R25.2, XTL5.1 (XTL1)
unnamed: LED5.2 (C-R), RN5.7 (2)
unnamed: LED5.1 (C-B), RN5.8 (2)
unnamed: LED5.3 (C-G), RN5.5 (2)
SCL: Q10.3 (D); also elsewhere on the board
SDA: Q9.3 (D); also elsewhere on the board

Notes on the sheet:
Payload Processor Node 5
ATmega328P Microcontroller
I2C Isolation
Status Display
Power Control
SMD3225-16MHZ 3.2 x 2.5mm crystal

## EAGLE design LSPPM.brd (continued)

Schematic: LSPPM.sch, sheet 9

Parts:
C18, C19: 22pF 0402; C0402
C20: 1uF 0603; C0603
H8: ICSP; M2X3-2MM
IC6: ATMEGA328P QFN32; MLF32
LED6: FREETRONICS-MASTER-V1_RGBLEDSMT; FREETRONICS-MASTER-V1_19-337
Q13, Q14: RJU003N03 N-MOSFET; SOT32-3
R29: 22K 0402; R0402
R30: 1M 0402; R0402
R31, R34: 10K 0402; R0402
RN6: 2K2; CAY16
SW6: ADG801 SOT23-6; SOT23-6
XTL6: SMD3225-16MHZ 3.2 x 2.5mm crystal; CRYSTAL-SMD-3X2

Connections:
5V: SW6.2 (S), SW6.6 (VDD); also elsewhere on the board
D31_N6_PWR: SW6.4 (IN); also elsewhere on the board
GND: C18.1, C19.1, C20.2, H8.6, IC6.3 (GND), IC6.5 (GND), IC6.21 (AGND), IC6.TGND (GND), RN6.1, SW6.3 (GND), XTL6.2 (GND), XTL6.4 (GND2); also elsewhere on the board
N6_5V: C20.1, H8.2, IC6.4 (VCC), IC6.6 (VCC), IC6.18 (AVCC), IC6.20 (AREF), LED6.5 (A-R), LED6.6 (A-G), Q13.1 (G), Q14.1 (G), R29.2, R31.2, R34.2, SW6.1 (D)
N6_A4_SDA: IC6.27 (PC4(ADC4/SDA)), Q13.2 (S), R31.1
N6_A5_SCL: IC6.28 (PC5(ADC5/SCL)), Q14.2 (S), R34.1
N6_D0_RX: IC6.30 (PD0(RXD)), RN6.4 (1); also elsewhere on the board
N6_D1_TX: IC6.31 (PD1(TXD)), RN6.2 (1); also elsewhere on the board
N6_D11_MOSI: H8.4, IC6.15 (PB3(MOSI/OC2))
N6_D12_MISO: H8.1, IC6.16 (PB4(MISO))
N6_D13_SCK: H8.3, IC6.17 (PB5(SCK)), LED6.4 (A-B)
N6_RESET: H8.5, IC6.29 (PC6(/RESET)), R29.1; also elsewhere on the board
unnamed: C19.2, IC6.8 (PB7(XTAL2/TOSC2)), R30.1, XTL6.3 (XTL2)
unnamed: C18.2, IC6.7 (PB6(XTAL1/TOSC1)), R30.2, XTL6.1 (XTL1)
unnamed: LED6.2 (C-R), RN6.7 (2)
unnamed: LED6.1 (C-B), RN6.8 (2)
unnamed: LED6.3 (C-G), RN6.5 (2)
SCL: Q14.3 (D); also elsewhere on the board
SDA: Q13.3 (D); also elsewhere on the board

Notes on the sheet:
Payload Processor Node 6
ATmega328P Microcontroller
I2C Isolation
Status Display
Power Control
SMD3225-16MHZ 3.2 x 2.5mm crystal

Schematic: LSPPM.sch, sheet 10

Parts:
C21, C22: 22pF 0402; C0402
C23: 1uF 0603; C0603
H9: ICSP; M2X3-2MM
IC7: ATMEGA328P QFN32; MLF32
LED7: FREETRONICS-MASTER-V1_RGBLEDSMT; FREETRONICS-MASTER-V1_19-337
Q15, Q16: RJU003N03 N-MOSFET; SOT32-3
R35: 22K 0402; R0402
R36: 1M 0402; R0402
R37, R38: 10K 0402; R0402
RN7: 2K2; CAY16
SW7: ADG801 SOT23-6; SOT23-6
XTL7: SMD3225-16MHZ 3.2 x 2.5mm crystal; CRYSTAL-SMD-3X2

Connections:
5V: SW7.2 (S), SW7.6 (VDD); also elsewhere on the board
D32_N7_PWR: SW7.4 (IN); also elsewhere on the board
GND: C21.1, C22.1, C23.2, H9.6, IC7.3 (GND), IC7.5 (GND), IC7.21 (AGND), IC7.TGND (GND), RN7.1, SW7.3 (GND), XTL7.2 (GND), XTL7.4 (GND2); also elsewhere on the board
N7_5V: C23.1, H9.2, IC7.4 (VCC), IC7.6 (VCC), IC7.18 (AVCC), IC7.20 (AREF), LED7.5 (A-R), LED7.6 (A-G), Q15.1 (G), Q16.1 (G), R35.2, R37.2, R38.2, SW7.1 (D)
N7_A4_SDA: IC7.27 (PC4(ADC4/SDA)), Q15.2 (S), R37.1
N7_A5_SCL: IC7.28 (PC5(ADC5/SCL)), Q16.2 (S), R38.1
N7_D0_RX: IC7.30 (PD0(RXD)), RN7.4 (1); also elsewhere on the board
N7_D1_TX: IC7.31 (PD1(TXD)), RN7.2 (1); also elsewhere on the board
N7_D11_MOSI: H9.4, IC7.15 (PB3(MOSI/OC2))
N7_D12_MISO: H9.1, IC7.16 (PB4(MISO))
N7_D13_SCK: H9.3, IC7.17 (PB5(SCK)), LED7.4 (A-B)
N7_RESET: H9.5, IC7.29 (PC6(/RESET)), R35.1; also elsewhere on the board
unnamed: C22.2, IC7.8 (PB7(XTAL2/TOSC2)), R36.1, XTL7.3 (XTL2)
unnamed: C21.2, IC7.7 (PB6(XTAL1/TOSC1)), R36.2, XTL7.1 (XTL1)
unnamed: LED7.2 (C-R), RN7.7 (2)
unnamed: LED7.1 (C-B), RN7.8 (2)
unnamed: LED7.3 (C-G), RN7.5 (2)
SCL: Q16.3 (D); also elsewhere on the board
SDA: Q15.3 (D); also elsewhere on the board

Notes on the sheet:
Payload Processor Node 7
ATmega328P Microcontroller
I2C Isolation
Status Display
Power Control
SMD3225-16MHZ 3.2 x 2.5mm crystal

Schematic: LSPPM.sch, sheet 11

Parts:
C24, C25: 22pF 0402; C0402
C26: 1uF 0603; C0603
H10: ICSP; M2X3-2MM
IC8: ATMEGA328P QFN32; MLF32
LED8: FREETRONICS-MASTER-V1_RGBLEDSMT; FREETRONICS-MASTER-V1_19-337
Q17, Q18: RJU003N03 N-MOSFET; SOT32-3
R39: 22K 0402; R0402
R40: 1M 0402; R0402
R41, R42: 10K 0402; R0402
RN8: 2K2; CAY16
SW8: ADG801 SOT23-6; SOT23-6
XTL8: SMD3225-16MHZ 3.2 x 2.5mm crystal; CRYSTAL-SMD-3X2

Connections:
5V: SW8.2 (S), SW8.6 (VDD); also elsewhere on the board
D33_N8_PWR: SW8.4 (IN); also elsewhere on the board
GND: C24.1, C25.1, C26.2, H10.6, IC8.3 (GND), IC8.5 (GND), IC8.21 (AGND), IC8.TGND (GND), RN8.1, SW8.3 (GND), XTL8.2 (GND), XTL8.4 (GND2); also elsewhere on the board
N8_5V: C26.1, H10.2, IC8.4 (VCC), IC8.6 (VCC), IC8.18 (AVCC), IC8.20 (AREF), LED8.5 (A-R), LED8.6 (A-G), Q17.1 (G), Q18.1 (G), R39.2, R41.2, R42.2, SW8.1 (D)
N8_A4_SDA: IC8.27 (PC4(ADC4/SDA)), Q17.2 (S), R41.1
N8_A5_SCL: IC8.28 (PC5(ADC5/SCL)), Q18.2 (S), R42.1
N8_D0_RX: IC8.30 (PD0(RXD)), RN8.4 (1); also elsewhere on the board
N8_D1_TX: IC8.31 (PD1(TXD)), RN8.2 (1); also elsewhere on the board
N8_D11_MOSI: H10.4, IC8.15 (PB3(MOSI/OC2))
N8_D12_MISO: H10.1, IC8.16 (PB4(MISO))
N8_D13_SCK: H10.3, IC8.17 (PB5(SCK)), LED8.4 (A-B)
N8_RESET: H10.5, IC8.29 (PC6(/RESET)), R39.1; also elsewhere on the board
unnamed: C25.2, IC8.8 (PB7(XTAL2/TOSC2)), R40.1, XTL8.3 (XTL2)
unnamed: C24.2, IC8.7 (PB6(XTAL1/TOSC1)), R40.2, XTL8.1 (XTL1)
unnamed: LED8.2 (C-R), RN8.7 (2)
unnamed: LED8.1 (C-B), RN8.8 (2)
unnamed: LED8.3 (C-G), RN8.5 (2)
SCL: Q18.3 (D); also elsewhere on the board
SDA: Q17.3 (D); also elsewhere on the board

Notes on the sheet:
Payload Processor Node 8
ATmega328P Microcontroller
I2C Isolation
Status Display
Power Control
SMD3225-16MHZ 3.2 x 2.5mm crystal

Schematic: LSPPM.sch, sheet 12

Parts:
C27, C28: 22pF 0402; C0402
C29: 1uF 0603; C0603
H11: ICSP; M2X3-2MM
IC9: ATMEGA328P QFN32; MLF32
LED9: FREETRONICS-MASTER-V1_RGBLEDSMT; FREETRONICS-MASTER-V1_19-337
Q19, Q20: RJU003N03 N-MOSFET; SOT32-3
R43: 22K 0402; R0402
R44: 1M 0402; R0402
R45, R46: 10K 0402; R0402
RN9: 2K2; CAY16
SW9: ADG801 SOT23-6; SOT23-6
XTL9: SMD3225-16MHZ 3.2 x 2.5mm crystal; CRYSTAL-SMD-3X2

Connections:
5V: SW9.2 (S), SW9.6 (VDD); also elsewhere on the board
D26_N9_PWR: SW9.4 (IN); also elsewhere on the board
GND: C27.1, C28.1, C29.2, H11.6, IC9.3 (GND), IC9.5 (GND), IC9.21 (AGND), IC9.TGND (GND), RN9.1, SW9.3 (GND), XTL9.2 (GND), XTL9.4 (GND2); also elsewhere on the board
N9_5V: C29.1, H11.2, IC9.4 (VCC), IC9.6 (VCC), IC9.18 (AVCC), IC9.20 (AREF), LED9.5 (A-R), LED9.6 (A-G), Q19.1 (G), Q20.1 (G), R43.2, R45.2, R46.2, SW9.1 (D)
N9_A4_SDA: IC9.27 (PC4(ADC4/SDA)), Q19.2 (S), R45.1
N9_A5_SCL: IC9.28 (PC5(ADC5/SCL)), Q20.2 (S), R46.1
N9_D0_RX: IC9.30 (PD0(RXD)), RN9.4 (1); also elsewhere on the board
N9_D1_TX: IC9.31 (PD1(TXD)), RN9.2 (1); also elsewhere on the board
N9_D11_MOSI: H11.4, IC9.15 (PB3(MOSI/OC2))
N9_D12_MISO: H11.1, IC9.16 (PB4(MISO))
N9_D13_SCK: H11.3, IC9.17 (PB5(SCK)), LED9.4 (A-B)
N9_RESET: H11.5, IC9.29 (PC6(/RESET)), R43.1; also elsewhere on the board
unnamed: C28.2, IC9.8 (PB7(XTAL2/TOSC2)), R44.1, XTL9.3 (XTL2)
unnamed: C27.2, IC9.7 (PB6(XTAL1/TOSC1)), R44.2, XTL9.1 (XTL1)
unnamed: LED9.2 (C-R), RN9.7 (2)
unnamed: LED9.1 (C-B), RN9.8 (2)
unnamed: LED9.3 (C-G), RN9.5 (2)
SCL: Q20.3 (D); also elsewhere on the board
SDA: Q19.3 (D); also elsewhere on the board

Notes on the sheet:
Payload Processor Node 9
ATmega328P Microcontroller
I2C Isolation
Status Display
Power Control
SMD3225-16MHZ 3.2 x 2.5mm crystal

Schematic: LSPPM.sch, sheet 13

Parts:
C30, C31: 22pF 0402; C0402
C32: 1uF 0603; C0603
H12: ICSP; M2X3-2MM
IC10: ATMEGA328P QFN32; MLF32
LED10: FREETRONICS-MASTER-V1_RGBLEDSMT; FREETRONICS-MASTER-V1_19-337
Q21, Q22: RJU003N03 N-MOSFET; SOT32-3
R47: 22K 0402; R0402
R48: 1M 0402; R0402
R49, R50: 10K 0402; R0402
RN10: 2K2; CAY16
SW10: ADG801 SOT23-6; SOT23-6
XTL10: SMD3225-16MHZ 3.2 x 2.5mm crystal; CRYSTAL-SMD-3X2

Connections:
5V: SW10.2 (S), SW10.6 (VDD); also elsewhere on the board
D27_N10_PWR: SW10.4 (IN); also elsewhere on the board
GND: C30.1, C31.1, C32.2, H12.6, IC10.3 (GND), IC10.5 (GND), IC10.21 (AGND), IC10.TGND (GND), RN10.1, SW10.3 (GND), XTL10.2 (GND), XTL10.4 (GND2); also elsewhere on the board
N10_5V: C32.1, H12.2, IC10.4 (VCC), IC10.6 (VCC), IC10.18 (AVCC), IC10.20 (AREF), LED10.5 (A-R), LED10.6 (A-G), Q21.1 (G), Q22.1 (G), R47.2, R49.2, R50.2, SW10.1 (D)
N10_A4_SDA: IC10.27 (PC4(ADC4/SDA)), Q21.2 (S), R49.1
N10_A5_SCL: IC10.28 (PC5(ADC5/SCL)), Q22.2 (S), R50.1
N10_D0_RX: IC10.30 (PD0(RXD)), RN10.4 (1); also elsewhere on the board
N10_D1_TX: IC10.31 (PD1(TXD)), RN10.2 (1); also elsewhere on the board
N10_D11_MOSI: H12.4, IC10.15 (PB3(MOSI/OC2))
N10_D12_MISO: H12.1, IC10.16 (PB4(MISO))
N10_D13_SCK: H12.3, IC10.17 (PB5(SCK)), LED10.4 (A-B)
N10_RESET: H12.5, IC10.29 (PC6(/RESET)), R47.1; also elsewhere on the board
unnamed: C31.2, IC10.8 (PB7(XTAL2/TOSC2)), R48.1, XTL10.3 (XTL2)
unnamed: C30.2, IC10.7 (PB6(XTAL1/TOSC1)), R48.2, XTL10.1 (XTL1)
unnamed: LED10.2 (C-R), RN10.7 (2)
unnamed: LED10.1 (C-B), RN10.8 (2)
unnamed: LED10.3 (C-G), RN10.5 (2)
SCL: Q22.3 (D); also elsewhere on the board
SDA: Q21.3 (D); also elsewhere on the board

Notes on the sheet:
Payload Processor Node 10
ATmega328P Microcontroller
I2C Isolation
Status Display
Power Control
SMD3225-16MHZ 3.2 x 2.5mm crystal

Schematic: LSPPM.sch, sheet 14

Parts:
C33, C34: 22pF 0402; C0402
C35: 1uF 0603; C0603
H13: ICSP; M2X3-2MM
IC11: ATMEGA328P QFN32; MLF32
LED11: FREETRONICS-MASTER-V1_RGBLEDSMT; FREETRONICS-MASTER-V1_19-337
Q23, Q24: RJU003N03 N-MOSFET; SOT32-3
R51: 22K 0402; R0402
R52: 1M 0402; R0402
R53, R54: 10K 0402; R0402
RN11: 2K2; CAY16
SW11: ADG801 SOT23-6; SOT23-6
XTL11: SMD3225-16MHZ 3.2 x 2.5mm crystal; CRYSTAL-SMD-3X2

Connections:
5V: SW11.2 (S), SW11.6 (VDD); also elsewhere on the board
D28_N11_PWR: SW11.4 (IN); also elsewhere on the board
GND: C33.1, C34.1, C35.2, H13.6, IC11.3 (GND), IC11.5 (GND), IC11.21 (AGND), IC11.TGND (GND), RN11.1, SW11.3 (GND), XTL11.2 (GND), XTL11.4 (GND2); also elsewhere on the board
N11_5V: C35.1, H13.2, IC11.4 (VCC), IC11.6 (VCC), IC11.18 (AVCC), IC11.20 (AREF), LED11.5 (A-R), LED11.6 (A-G), Q23.1 (G), Q24.1 (G), R51.2, R53.2, R54.2, SW11.1 (D); also elsewhere on the board
N11_A4_SDA: IC11.27 (PC4(ADC4/SDA)), Q23.2 (S), R53.1
N11_A5_SCL: IC11.28 (PC5(ADC5/SCL)), Q24.2 (S), R54.1
N11_D0_RX: IC11.30 (PD0(RXD)), RN11.4 (1); also elsewhere on the board
N11_D1_TX: IC11.31 (PD1(TXD)), RN11.2 (1); also elsewhere on the board
N11_D6: IC11.10 (PD6(AIN0)); also elsewhere on the board
N11_D7: IC11.11 (PD7(AIN1)); also elsewhere on the board
N11_D11_MOSI: H13.4, IC11.15 (PB3(MOSI/OC2))
N11_D12_MISO: H13.1, IC11.16 (PB4(MISO))
N11_D13_SCK: H13.3, IC11.17 (PB5(SCK)), LED11.4 (A-B)
N11_RESET: H13.5, IC11.29 (PC6(/RESET)), R51.1; also elsewhere on the board
unnamed: C34.2, IC11.8 (PB7(XTAL2/TOSC2)), R52.1, XTL11.3 (XTL2)
unnamed: C33.2, IC11.7 (PB6(XTAL1/TOSC1)), R52.2, XTL11.1 (XTL1)
unnamed: LED11.2 (C-R), RN11.7 (2)
unnamed: LED11.1 (C-B), RN11.8 (2)
unnamed: LED11.3 (C-G), RN11.5 (2)
SCL: Q24.3 (D); also elsewhere on the board
SDA: Q23.3 (D); also elsewhere on the board

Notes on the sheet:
Payload Processor Node 11
ATmega328P Microcontroller
I2C Isolation
Status Display
Power Control
SMD3225-16MHZ 3.2 x 2.5mm crystal
Note: Node 11 is connected via serial level shifters to the GPS module

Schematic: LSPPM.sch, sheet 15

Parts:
C36, C37: 22pF 0402; C0402
C38: 1uF 0603; C0603
H14: ICSP; M2X3-2MM
IC12: ATMEGA328P QFN32; MLF32
LED12: FREETRONICS-MASTER-V1_RGBLEDSMT; FREETRONICS-MASTER-V1_19-337
Q25, Q26: RJU003N03 N-MOSFET; SOT32-3
R55: 22K 0402; R0402
R56: 1M 0402; R0402
R57, R58: 10K 0402; R0402
RN12: 2K2; CAY16
SW12: ADG801 SOT23-6; SOT23-6
XTL12: SMD3225-16MHZ 3.2 x 2.5mm crystal; CRYSTAL-SMD-3X2

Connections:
5V: SW12.2 (S), SW12.6 (VDD); also elsewhere on the board
D29_N12_PWR: SW12.4 (IN); also elsewhere on the board
GND: C36.1, C37.1, C38.2, H14.6, IC12.3 (GND), IC12.5 (GND), IC12.21 (AGND), IC12.TGND (GND), RN12.1, SW12.3 (GND), XTL12.2 (GND), XTL12.4 (GND2); also elsewhere on the board
N12_5V: C38.1, H14.2, IC12.4 (VCC), IC12.6 (VCC), IC12.18 (AVCC), IC12.20 (AREF), LED12.5 (A-R), LED12.6 (A-G), Q25.1 (G), Q26.1 (G), R55.2, R57.2, R58.2, SW12.1 (D)
N12_A4_SDA: IC12.27 (PC4(ADC4/SDA)), Q25.2 (S), R57.1
N12_A5_SCL: IC12.28 (PC5(ADC5/SCL)), Q26.2 (S), R58.1
N12_D0_RX: IC12.30 (PD0(RXD)), RN12.4 (1); also elsewhere on the board
N12_D1_TX: IC12.31 (PD1(TXD)), RN12.2 (1); also elsewhere on the board
N12_D11_MOSI: H14.4, IC12.15 (PB3(MOSI/OC2))
N12_D12_MISO: H14.1, IC12.16 (PB4(MISO))
N12_D13_SCK: H14.3, IC12.17 (PB5(SCK)), LED12.4 (A-B)
N12_RESET: H14.5, IC12.29 (PC6(/RESET)), R55.1; also elsewhere on the board
unnamed: C37.2, IC12.8 (PB7(XTAL2/TOSC2)), R56.1, XTL12.3 (XTL2)
unnamed: C36.2, IC12.7 (PB6(XTAL1/TOSC1)), R56.2, XTL12.1 (XTL1)
unnamed: LED12.2 (C-R), RN12.7 (2)
unnamed: LED12.1 (C-B), RN12.8 (2)
unnamed: LED12.3 (C-G), RN12.5 (2)
SCL: Q26.3 (D); also elsewhere on the board
SDA: Q25.3 (D); also elsewhere on the board

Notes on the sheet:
Payload Processor Node 12
ATmega328P Microcontroller
I2C Isolation
Status Display
Power Control
SMD3225-16MHZ 3.2 x 2.5mm crystal

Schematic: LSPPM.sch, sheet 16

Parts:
C41, C42: 22pF 0402; C0402
C43: 1uF 0603; C0603
H15: ICSP; M2X3-2MM
IC13: ATMEGA328P QFN32; MLF32
LED13: FREETRONICS-MASTER-V1_RGBLEDSMT; FREETRONICS-MASTER-V1_19-337
Q27, Q28: RJU003N03 N-MOSFET; SOT32-3
R60: 22K 0402; R0402
R61: 1M 0402; R0402
R62, R63: 10K 0402; R0402
RN13: 2K2; CAY16
SW13: ADG801 SOT23-6; SOT23-6
XTL13: SMD3225-16MHZ 3.2 x 2.5mm crystal; CRYSTAL-SMD-3X2

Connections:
5V: SW13.2 (S), SW13.6 (VDD); also elsewhere on the board
D22_N13_PWR: SW13.4 (IN); also elsewhere on the board
GND: C41.1, C42.1, C43.2, H15.6, IC13.3 (GND), IC13.5 (GND), IC13.21 (AGND), IC13.TGND (GND), RN13.1, SW13.3 (GND), XTL13.2 (GND), XTL13.4 (GND2); also elsewhere on the board
N13_5V: C43.1, H15.2, IC13.4 (VCC), IC13.6 (VCC), IC13.18 (AVCC), IC13.20 (AREF), LED13.5 (A-R), LED13.6 (A-G), Q27.1 (G), Q28.1 (G), R60.2, R62.2, R63.2, SW13.1 (D)
N13_A4_SDA: IC13.27 (PC4(ADC4/SDA)), Q27.2 (S), R62.1
N13_A5_SCL: IC13.28 (PC5(ADC5/SCL)), Q28.2 (S), R63.1
N13_D0_RX: IC13.30 (PD0(RXD)), RN13.4 (1); also elsewhere on the board
N13_D1_TX: IC13.31 (PD1(TXD)), RN13.2 (1); also elsewhere on the board
N13_D11_MOSI: H15.4, IC13.15 (PB3(MOSI/OC2))
N13_D12_MISO: H15.1, IC13.16 (PB4(MISO))
N13_D13_SCK: H15.3, IC13.17 (PB5(SCK)), LED13.4 (A-B)
N13_RESET: H15.5, IC13.29 (PC6(/RESET)), R60.1; also elsewhere on the board
unnamed: C42.2, IC13.8 (PB7(XTAL2/TOSC2)), R61.1, XTL13.3 (XTL2)
unnamed: C41.2, IC13.7 (PB6(XTAL1/TOSC1)), R61.2, XTL13.1 (XTL1)
unnamed: LED13.2 (C-R), RN13.7 (2)
unnamed: LED13.1 (C-B), RN13.8 (2)
unnamed: LED13.3 (C-G), RN13.5 (2)
SCL: Q28.3 (D); also elsewhere on the board
SDA: Q27.3 (D); also elsewhere on the board

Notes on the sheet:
Payload Processor Node 13
ATmega328P Microcontroller
I2C Isolation
Status Display
Power Control
SMD3225-16MHZ 3.2 x 2.5mm crystal

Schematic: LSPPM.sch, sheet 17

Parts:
C44, C45: 22pF 0402; C0402
C46: 1uF 0603; C0603
H16: ICSP; M2X3-2MM
IC14: ATMEGA328P QFN32; MLF32
LED14: FREETRONICS-MASTER-V1_RGBLEDSMT; FREETRONICS-MASTER-V1_19-337
Q29, Q30: RJU003N03 N-MOSFET; SOT32-3
R64: 22K 0402; R0402
R65: 1M 0402; R0402
R66, R67: 10K 0402; R0402
RN14: 2K2; CAY16
SW14: ADG801 SOT23-6; SOT23-6
XTL14: SMD3225-16MHZ 3.2 x 2.5mm crystal; CRYSTAL-SMD-3X2

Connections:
5V: SW14.2 (S), SW14.6 (VDD); also elsewhere on the board
D23_N14_PWR: SW14.4 (IN); also elsewhere on the board
GND: C44.1, C45.1, C46.2, H16.6, IC14.3 (GND), IC14.5 (GND), IC14.21 (AGND), IC14.TGND (GND), RN14.1, SW14.3 (GND), XTL14.2 (GND), XTL14.4 (GND2); also elsewhere on the board
N14_5V: C46.1, H16.2, IC14.4 (VCC), IC14.6 (VCC), IC14.18 (AVCC), IC14.20 (AREF), LED14.5 (A-R), LED14.6 (A-G), Q29.1 (G), Q30.1 (G), R64.2, R66.2, R67.2, SW14.1 (D)
N14_A4_SDA: IC14.27 (PC4(ADC4/SDA)), Q29.2 (S), R66.1
N14_A5_SCL: IC14.28 (PC5(ADC5/SCL)), Q30.2 (S), R67.1
N14_D0_RX: IC14.30 (PD0(RXD)), RN14.4 (1); also elsewhere on the board
N14_D1_TX: IC14.31 (PD1(TXD)), RN14.2 (1); also elsewhere on the board
N14_D11_MOSI: H16.4, IC14.15 (PB3(MOSI/OC2))
N14_D12_MISO: H16.1, IC14.16 (PB4(MISO))
N14_D13_SCK: H16.3, IC14.17 (PB5(SCK)), LED14.4 (A-B)
N14_RESET: H16.5, IC14.29 (PC6(/RESET)), R64.1; also elsewhere on the board
unnamed: C45.2, IC14.8 (PB7(XTAL2/TOSC2)), R65.1, XTL14.3 (XTL2)
unnamed: C44.2, IC14.7 (PB6(XTAL1/TOSC1)), R65.2, XTL14.1 (XTL1)
unnamed: LED14.2 (C-R), RN14.7 (2)
unnamed: LED14.1 (C-B), RN14.8 (2)
unnamed: LED14.3 (C-G), RN14.5 (2)
SCL: Q30.3 (D); also elsewhere on the board
SDA: Q29.3 (D); also elsewhere on the board

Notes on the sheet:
Payload Processor Node 14
ATmega328P Microcontroller
I2C Isolation
Status Display
Power Control
SMD3225-16MHZ 3.2 x 2.5mm crystal

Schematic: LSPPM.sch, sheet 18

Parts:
C47, C48: 22pF 0402; C0402
C49: 1uF 0603; C0603
H17: ICSP; M2X3-2MM
IC15: ATMEGA328P QFN32; MLF32
LED15: FREETRONICS-MASTER-V1_RGBLEDSMT; FREETRONICS-MASTER-V1_19-337
Q31, Q32: RJU003N03 N-MOSFET; SOT32-3
R68: 22K 0402; R0402
R69: 1M 0402; R0402
R70, R71: 10K 0402; R0402
RN15: 2K2; CAY16
SW15: ADG801 SOT23-6; SOT23-6
XTL15: SMD3225-16MHZ 3.2 x 2.5mm crystal; CRYSTAL-SMD-3X2

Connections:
5V: SW15.2 (S), SW15.6 (VDD); also elsewhere on the board
D24_N15_PWR: SW15.4 (IN); also elsewhere on the board
GND: C47.1, C48.1, C49.2, H17.6, IC15.3 (GND), IC15.5 (GND), IC15.21 (AGND), IC15.TGND (GND), RN15.1, SW15.3 (GND), XTL15.2 (GND), XTL15.4 (GND2); also elsewhere on the board
N15_5V: C49.1, H17.2, IC15.4 (VCC), IC15.6 (VCC), IC15.18 (AVCC), IC15.20 (AREF), LED15.5 (A-R), LED15.6 (A-G), Q31.1 (G), Q32.1 (G), R68.2, R70.2, R71.2, SW15.1 (D)
N15_A4_SDA: IC15.27 (PC4(ADC4/SDA)), Q31.2 (S), R70.1
N15_A5_SCL: IC15.28 (PC5(ADC5/SCL)), Q32.2 (S), R71.1
N15_D0_RX: IC15.30 (PD0(RXD)), RN15.4 (1); also elsewhere on the board
N15_D1_TX: IC15.31 (PD1(TXD)), RN15.2 (1); also elsewhere on the board
N15_D11_MOSI: H17.4, IC15.15 (PB3(MOSI/OC2))
N15_D12_MISO: H17.1, IC15.16 (PB4(MISO))
N15_D13_SCK: H17.3, IC15.17 (PB5(SCK)), LED15.4 (A-B)
N15_RESET: H17.5, IC15.29 (PC6(/RESET)), R68.1; also elsewhere on the board
unnamed: C48.2, IC15.8 (PB7(XTAL2/TOSC2)), R69.1, XTL15.3 (XTL2)
unnamed: C47.2, IC15.7 (PB6(XTAL1/TOSC1)), R69.2, XTL15.1 (XTL1)
unnamed: LED15.2 (C-R), RN15.7 (2)
unnamed: LED15.1 (C-B), RN15.8 (2)
unnamed: LED15.3 (C-G), RN15.5 (2)
SCL: Q32.3 (D); also elsewhere on the board
SDA: Q31.3 (D); also elsewhere on the board

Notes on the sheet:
Payload Processor Node 15
ATmega328P Microcontroller
I2C Isolation
Status Display
Power Control
SMD3225-16MHZ 3.2 x 2.5mm crystal

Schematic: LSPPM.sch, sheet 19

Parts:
C50, C56: 22pF 0402; C0402
C57: 1uF 0603; C0603
H18: ICSP; M2X3-2MM
IC16: ATMEGA328P QFN32; MLF32
LED16: FREETRONICS-MASTER-V1_RGBLEDSMT; FREETRONICS-MASTER-V1_19-337
Q33, Q34: RJU003N03 N-MOSFET; SOT32-3
R72: 22K 0402; R0402
R73: 1M 0402; R0402
R74, R76: 10K 0402; R0402
RN16: 2K2; CAY16
SW16: ADG801 SOT23-6; SOT23-6
XTL16: SMD3225-16MHZ 3.2 x 2.5mm crystal; CRYSTAL-SMD-3X2

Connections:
5V: SW16.2 (S), SW16.6 (VDD); also elsewhere on the board
D25_N16_PWR: SW16.4 (IN); also elsewhere on the board
GND: C50.1, C56.1, C57.2, H18.6, IC16.3 (GND), IC16.5 (GND), IC16.21 (AGND), IC16.TGND (GND), RN16.1, SW16.3 (GND), XTL16.2 (GND), XTL16.4 (GND2); also elsewhere on the board
N16_5V: C57.1, H18.2, IC16.4 (VCC), IC16.6 (VCC), IC16.18 (AVCC), IC16.20 (AREF), LED16.5 (A-R), LED16.6 (A-G), Q33.1 (G), Q34.1 (G), R72.2, R74.2, R76.2, SW16.1 (D)
N16_A4_SDA: IC16.27 (PC4(ADC4/SDA)), Q33.2 (S), R74.1
N16_A5_SCL: IC16.28 (PC5(ADC5/SCL)), Q34.2 (S), R76.1
N16_D0_RX: IC16.30 (PD0(RXD)), RN16.4 (1); also elsewhere on the board
N16_D1_TX: IC16.31 (PD1(TXD)), RN16.2 (1); also elsewhere on the board
N16_D11_MOSI: H18.4, IC16.15 (PB3(MOSI/OC2))
N16_D12_MISO: H18.1, IC16.16 (PB4(MISO))
N16_D13_SCK: H18.3, IC16.17 (PB5(SCK)), LED16.4 (A-B)
N16_RESET: H18.5, IC16.29 (PC6(/RESET)), R72.1; also elsewhere on the board
unnamed: C56.2, IC16.8 (PB7(XTAL2/TOSC2)), R73.1, XTL16.3 (XTL2)
unnamed: C50.2, IC16.7 (PB6(XTAL1/TOSC1)), R73.2, XTL16.1 (XTL1)
unnamed: LED16.2 (C-R), RN16.7 (2)
unnamed: LED16.1 (C-B), RN16.8 (2)
unnamed: LED16.3 (C-G), RN16.5 (2)
SCL: Q34.3 (D); also elsewhere on the board
SDA: Q33.3 (D); also elsewhere on the board

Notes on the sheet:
Payload Processor Node 16
ATmega328P Microcontroller
I2C Isolation
Status Display
Power Control
SMD3225-16MHZ 3.2 x 2.5mm crystal

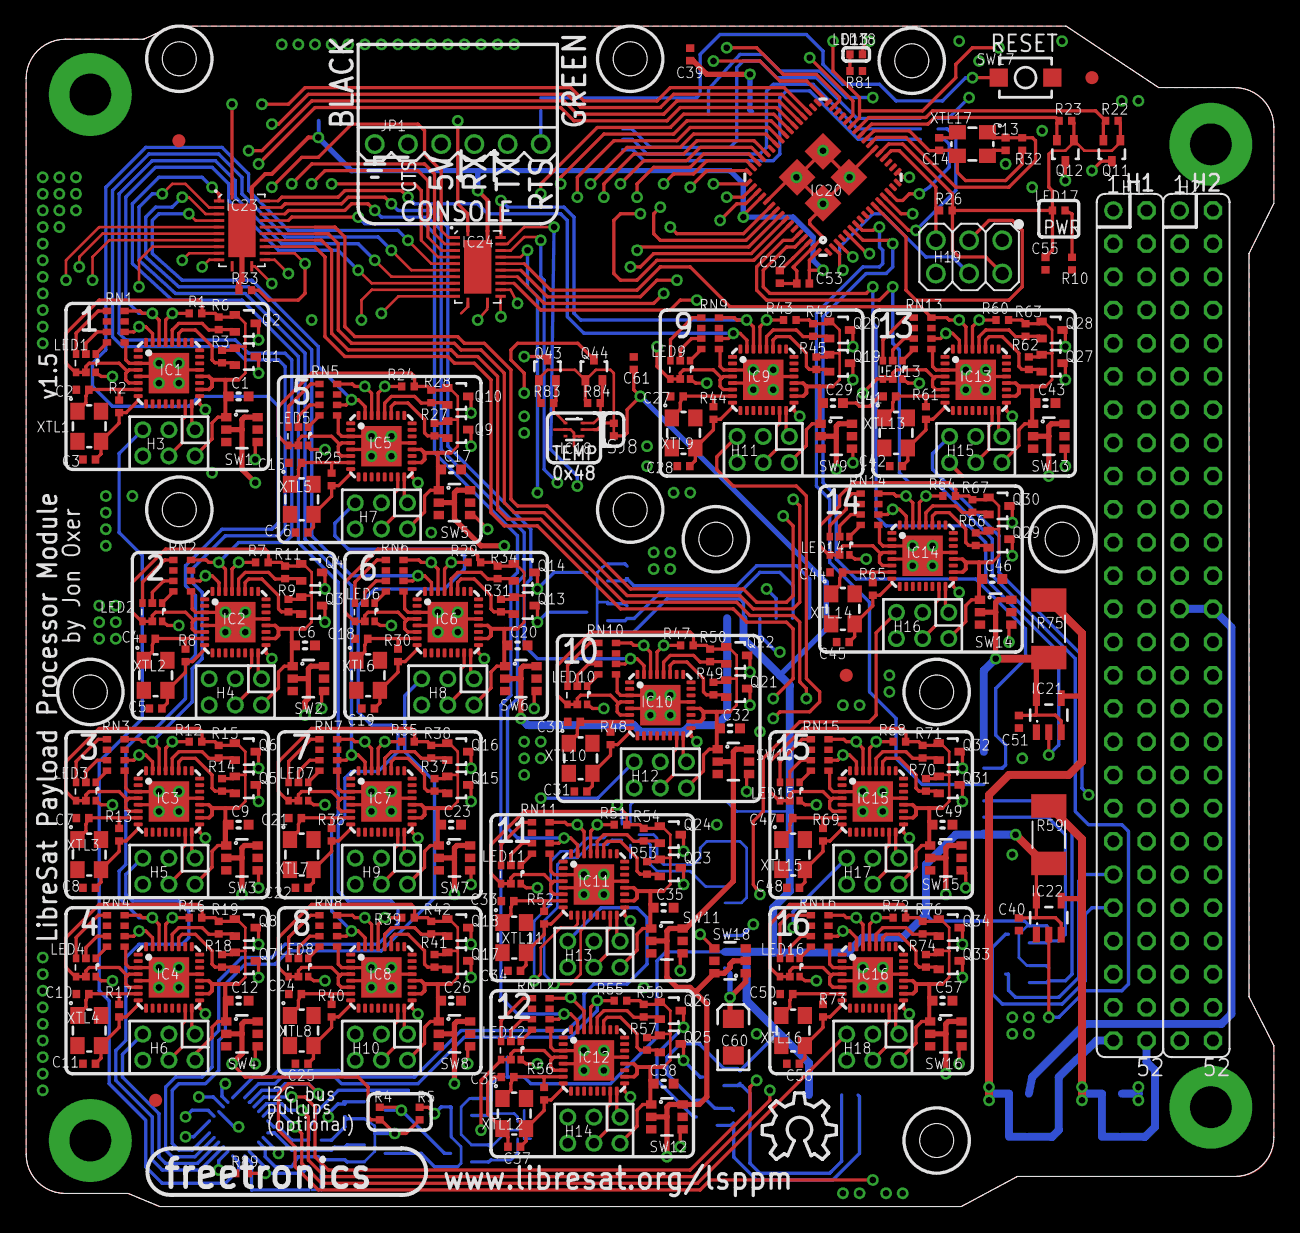
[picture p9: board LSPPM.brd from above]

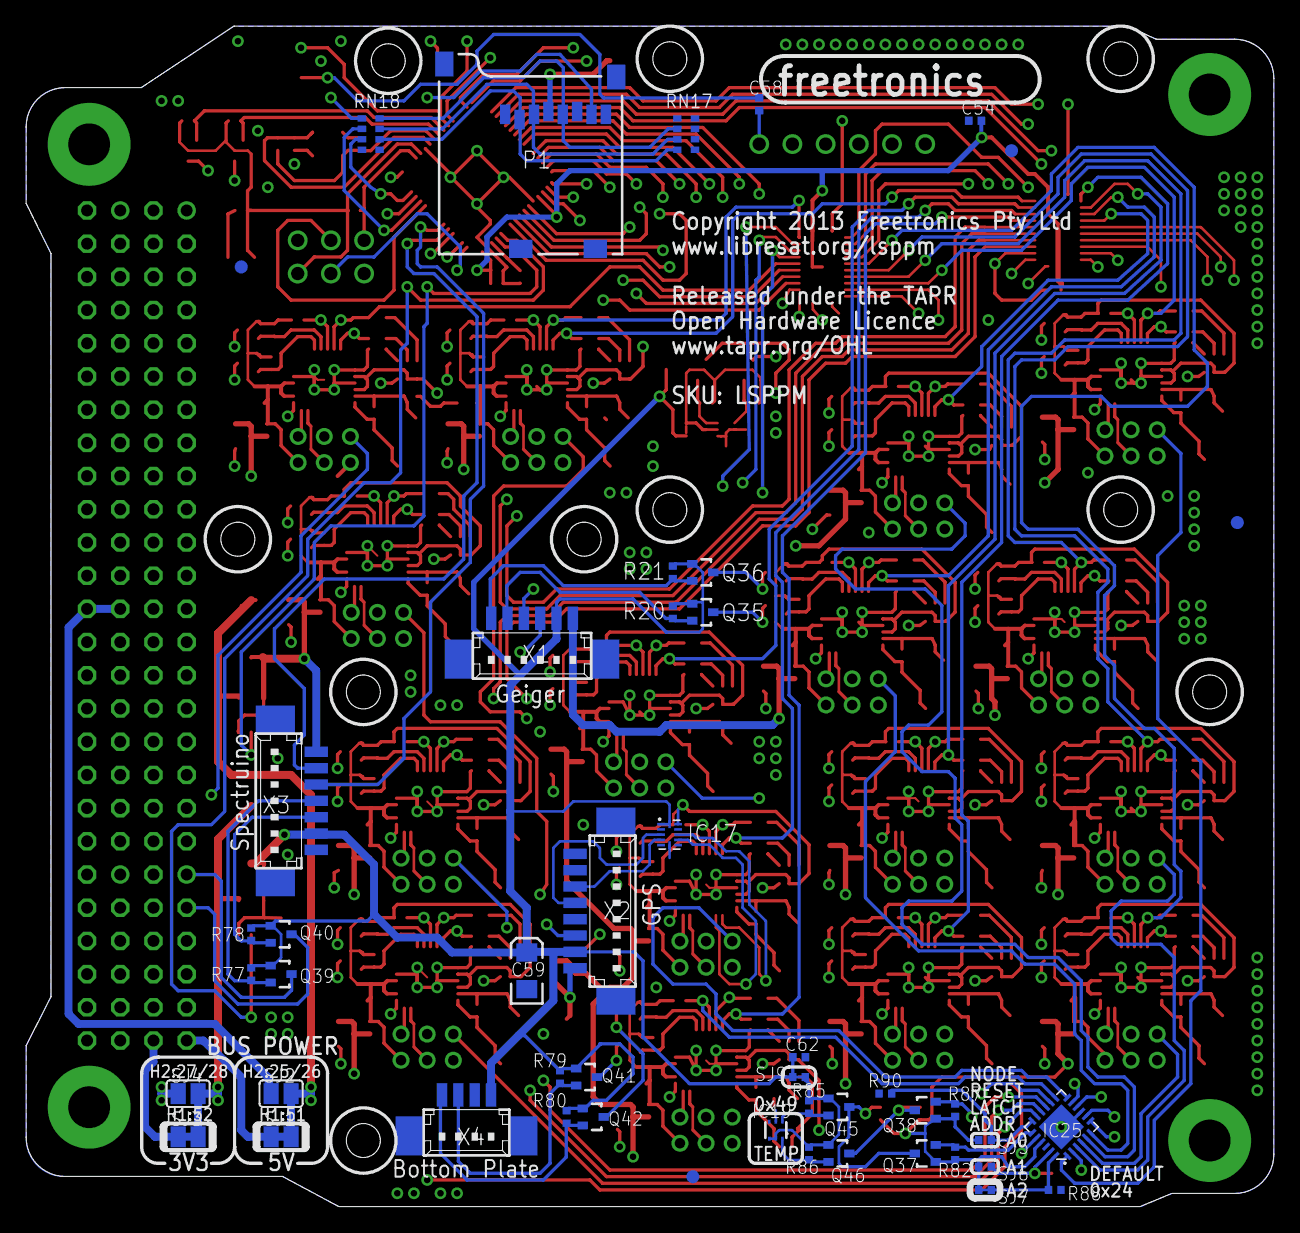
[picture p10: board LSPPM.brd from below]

Board: 4 copper layers, 95.5 x 90.3 mm, 341 parts (48 on the bottom side), 306 nets.

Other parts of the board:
U$33: OSHW_10X200_NOTEXT

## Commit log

2012-11-29 Initial project import
    [ArduSatMultipleProcessorModule.brd, ArduSatMultipleProcessorModule.sch]
2012-11-29 Testing replacement of latches using ATmega328
    [ArduSatMultipleProcessorModule.brd, ArduSatMultipleProcessorModule.sch]
2012-11-30 Added alternative supervisor node
    [ArduSatMultipleProcessorModule.brd, ArduSatMultipleProcessorModule.sch]
2012-12-02 Added VCC control for nodes 0 and 1
    [ArduSatMultipleProcessorModule.brd, ArduSatMultipleProcessorModule.sch]
2012-12-03 Supervisor now has control of both node power and serial comms
    [ArduSatMultipleProcessorModule.brd, ArduSatMultipleProcessorModule.sch]
2012-12-03 Removed direct control option for UART MUX and power
    [ArduSatMultipleProcessorModule.brd, ArduSatMultipleProcessorModule.sch]
2012-12-03 Experiments with node layout
    [ArduSatMultipleProcessorModule.brd, ArduSatMultipleProcessorModule.sch]
2012-12-03 Experiments in node dimensions and layout
    [ArduSatMultipleProcessorModule.brd, ArduSatMultipleProcessorModule.sch]
2012-12-04 Added parts for remaining nodes
    [ArduSatMultipleProcessorModule.brd, ArduSatMultipleProcessorModule.sch]
2012-12-05 Routing processor nodes
    [ArduSatMultipleProcessorModule.brd, ArduSatMultipleProcessorModule.sch]
2012-12-08 Moved nodes back down to lower part of module
    [ArduSatMultipleProcessorModule.brd]
2012-12-08 Experiments with arrangements of UART and PWR control
    [ArduSatMultipleProcessorModule.brd]
2013-01-05 Restructured project as payload module with duplicated payload nodes
    [ArduSatPayloadModule.brd, ArduSatPayloadModule.sch]
2013-01-05 Deleted old project files
    [ArduSatMultipleProcessorModule.brd, ArduSatMultipleProcessorModule.sch]
2013-01-08 Placement and routing
    [ArduSatPayloadModule.brd, ArduSatPayloadModule.sch]
2013-01-08 Renamed project files
    [ArduSatPayloadProcessorModule.brd, ArduSatPayloadProcessorModule.sch]
2013-01-10 ERC and DRC for production
    [ArduSatPayloadProcessorModule.brd, ArduSatPayloadProcessorModule.sch]
2013-01-17 Fix footprint for RGB LED
    [ArduSatPayloadProcessorModule.brd, ArduSatPayloadProcessorModule.sch]
2013-02-14 Fixed ISP pin assignment Added D13 LED to supervisor Fixed TX/RX from supervisor to multiplexers Replaced 4-pin debug connector with 6-pin connector in FTDI-type format Linked supervisor reset to deb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
    [ArduSatPayloadProcessorModule.brd, ArduSatPayloadProcessorModule.sch]
2013-02-16 Added labels for power source selection jumpers; added parts for node reset latch
    [ArduSatPayloadProcessorModule.brd, ArduSatPayloadProcessorModule.sch]
2013-02-16 Start of placement and fan-out of node reset latch
    [ArduSatPayloadProcessorModule.brd, ArduSatPayloadProcessorModule.sch]
2013-02-17 Finished routing latch for resetting nodes
    [ArduSatPayloadProcessorModule.brd]
2013-02-17 Clearance and label improvements
    [ArduSatPayloadProcessorModule.brd, ArduSatPayloadProcessorModule.sch]
2013-02-18 Re-routed around MCU GND pads and improved footprints
    [ArduSatPayloadProcessorModule.brd, ArduSatPayloadProcessorModule.sch]
2013-02-18 Clearances and DRC for v1.1 release
    [ArduSatPayloadProcessorModule.brd]
2013-02-18 Switched PWR LED to 0402
    [ArduSatPayloadProcessorModule.brd, ArduSatPayloadProcessorModule.sch]
2013-02-21 Release 1.2: power jumpers on TMP102s; clearances
    [ArduSatPayloadProcessorModule.brd, ArduSatPayloadProcessorModule.sch]
2013-02-21 Added PDF of schematic
2017-08-24 Updated README and board files for public release
    [ArduSatPayloadProcessorModule.brd, LSPPM.brd, LSPPM.sch]
2019-09-01 Replaced most parts using SuperHouse library to add 3D models
    [LSPPM.brd, LSPPM.sch]

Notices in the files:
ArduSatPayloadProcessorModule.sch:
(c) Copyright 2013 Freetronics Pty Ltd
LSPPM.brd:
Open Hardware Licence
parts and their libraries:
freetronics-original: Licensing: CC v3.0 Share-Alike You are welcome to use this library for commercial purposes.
